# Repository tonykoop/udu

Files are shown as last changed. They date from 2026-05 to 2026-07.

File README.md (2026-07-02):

# Udu — Slip-Cast Ceramic Vessel Drum Family

> *Engineering documentation for a 3D-printed-master, plaster-mold, cone-6-stoneware slip-cast udu drum family — from dual-Helmholtz physics through the parametric design table to a manufacturable build packet.*

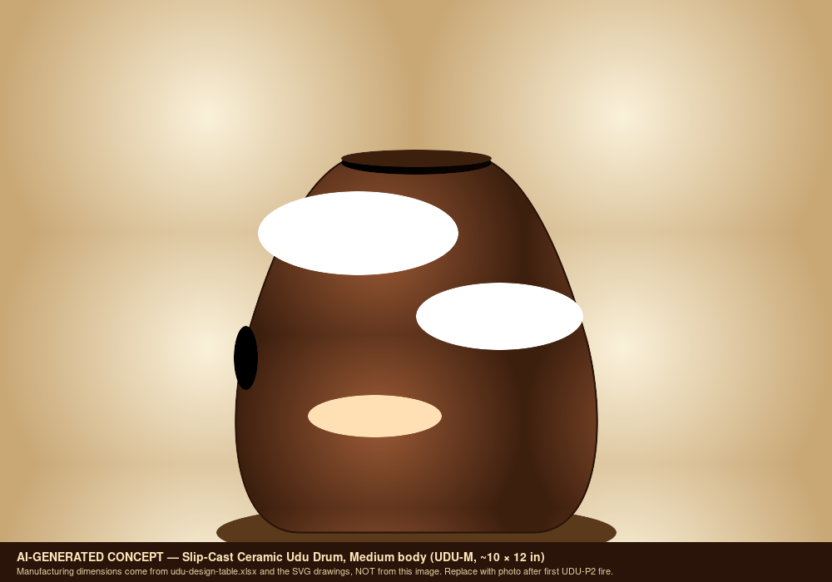
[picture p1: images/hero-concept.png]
Hero — AI-generated concept render of a Medium slip-cast udu (placeholder until first prototype is photographed)

*AI-generated concept render — replace with photo of first UDU-P2 (Medium) prototype after firing. Manufacturing dimensions come from the parametric design table, not from this image.*

## What this is

Engineering documentation for a four-size family (Small / Medium / Large / XL) of slip-cast ceramic udu drums, built around the **dual-Helmholtz coupled-resonator** model and a 3D-printed-master / plaster-mold / Cone-6-stoneware production pipeline. The repository combines:

1. **A parametric design table** ([`udu-design-table.xlsx`](udu-design-table.xlsx)) — body diameter, body height, wall thickness, mouth diameter, side-hole diameter, shape factor, shrinkage, and a four-size family-spec block with target mouth-tone and side-tone frequencies. Master scale factor `1/(1 - measured_shrinkage)` is parameterized; for a 12% shrinkage assumption, the master scales at ~1.136×.
2. **A v4.1 family-spec block** ([`family-spec.csv`](family-spec.csv)) — one row per family member (UDU-S/M/L/XL) with target frequencies, predicted frequencies from the dual-Helmholtz formula, cents-error per port, and the chamber-volume / port-area dimensions that drive both `cad/sw-design-table.xlsx` and `drawings/`.
3. **A full build packet** ([`design.md`](design.md), [`bom.csv`](bom.csv), [`sourcing.csv`](sourcing.csv), [`cut-list.csv`](cut-list.csv), [`validation.csv`](validation.csv), [`assembly-manual.md`](assembly-manual.md), [`supplier-rfq.md`](supplier-rfq.md), [`drawing-brief.md`](drawing-brief.md), [`visual-bom-brief.md`](visual-bom-brief.md), [`wolfram-starter.wl`](wolfram-starter.wl), [`risks.md`](risks.md)) — the same scaffold used across the [`tonykoop`](https://github.com/tonykoop) musical-instrument catalogue, with v4 red-team risk register added.
4. **A SolidWorks reference** ([`sw-reference/`](sw-reference/), [`cad/sw-design-table.xlsx`](cad/sw-design-table.xlsx)) — MasterLayout convention, global-equation list, design-table import procedure, and `Extract_Dimensions.swp` macro checklist. Round-trips `family-spec.csv` ↔ SolidWorks via the v4.1 SW workflow.
5. **A capstone slide deck, printable shop packet, and build-log site** ([`capstone-deck.pptx`](capstone-deck.pptx), [`print-packet.pdf`](print-packet.pdf), [`site/index.html`](site/index.html)) — three recruiter-facing artifacts that show the design is documented well enough that someone else could build it. The site is GitHub Pages compatible — drop `site/` into `docs/` to publish.

Sister repos: [`gemshorn`](https://github.com/tonykoop/gemshorn) (slip-cast horn-flute mold workflow), [`ocarina`](https://github.com/tonykoop/ocarina) (single-Helmholtz vessel-flute, sister slip-cast target), [`transverse-flute`](https://github.com/tonykoop/transverse-flute) (slip-cast workflow at larger scale), [`djembe`](https://github.com/tonykoop/djembe) (where Helmholtz-cavity-resonator analysis was originally derived for the bass tone), and [`instrument-maker`](https://github.com/tonykoop/instrument-maker) (the agent skill that generated this packet).

## Background — what makes the udu different

The udu (Igbo: *ụdụ*, "vessel") is a Nigerian clay-vessel drum: a closed ceramic body with a mouth at the top and a single side hole. Striking the mouth with a flat hand produces one resonant tone; striking the side hole produces another; opening, closing, and partly hand-covering each port lets the player slide and sweep between the two pitches. **It is not a generic ceramic bass pot.** Its lineage is specific and the documentation here treats that lineage as fact, not as marketing copy.

The governing model is **two coupled Helmholtz resonators sharing a chamber volume**:

```
f_top  = c/(2π) · √( A_top  / (V · L_top)  )
f_side = c/(2π) · √( A_side / (V · L_side) )
```

with `L = wall_thickness + 0.6·√(A/π)` (flanged-port end correction) and a coupling term that becomes important when both ports are partly open. Single-port formulas are useful **first-order** targets; the coupled-mode behavior — and especially the perceived pitch when a player's hand partly covers either port — has to be measured empirically. See [`design.md`](design.md) and [`wolfram-starter.wl`](wolfram-starter.wl) for the full treatment, including a placeholder eigenvalue model for coupled frequencies.

The practical consequence is that udu tuning is **two parametric pitches plus a player-coupled middle range**. Body volume sets the bass-end ceiling; port diameters set the upper bound; wall thickness and shape factor are secondary. Hand coupling is a sweep, not a discrete control — which is why the design table targets fall within ±50 ¢ rather than the ±25 ¢ used for fixed-pitch instruments like the ocarina.

## Family targets

The first prototype is the **Medium** body (10 in dia × 12 in tall, target mouth tone B3 ≈ 247 Hz, side tone G3 ≈ 196 Hz, chamber volume ≈ 440 in³). Once Medium voicing is stable, the same parametric model drives Small / Large / XL — see [`design.md`](design.md) and the family-spec block of [`udu-design-table.xlsx`](udu-design-table.xlsx).

| Model | Body diameter | Body height | Volume | Mouth tone | Side tone | Use |
|---|---:|---:|---:|---|---|---|
| **Small** | 8 in | 10 in | ~235 in³ | D♯4 | A3 | Tabletop, high tones |
| **Medium** *(prototype 1)* | 10 in | 12 in | ~440 in³ | B3 | G3 | Most versatile standard size |
| **Large** | 12 in | 14 in | ~739 in³ | G♯3 | D3 | Deep bass, traditional feel |
| **XL** | 14 in | 16 in | ~1149 in³ | F3 | C3 | Concert bass; needs stand |

Prototype ladder:

| Prototype | Goal | Success criteria |
|---|---|---|
| **UDU-P0** cup/port tile | Validate clay wall + tap behavior | No cracks; clear ceramic tap; clean port edge |
| **UDU-P1** Small body | Validate slip casting + side-hole slap | Measurable Helmholtz tones, comfortable slap edge |
| **UDU-P2** Medium body | Hit workbook Medium target | Mouth and side tones within ±50 ¢ post-bisque |
| **UDU-P3** Water udu | Pitch-bending volume variant | Smooth tilt-bend without leaking |
| **UDU-P4** Family molds | Scale S/M/L/XL | Predictable pitch trend across sizes |

## Hardware alignment — Bambu printer + ceramic kiln

This repo is one of the **slip-casting targets** for the in-flight Bambu printer + kiln pipeline. The build chain is:

1. Parametric design table sets fired-body dimensions.
2. Master scale factor `1/(1 - measured_shrinkage)` scales the master STL.
3. Bambu print master halves in PLA (or sealable resin); sand layer lines and seal. *Note: the Medium body is right at the edge of the Bambu X1C build envelope; XL will need a print farm split or outsourced master.*
4. Two-piece plaster mother mold around the sealed master.
5. Slip-cast Cone 6 stoneware → demold leather-hard → cut side hole undersized → bisque → tune → glaze (exterior only) → final fire.
6. Validate against [`validation.csv`](validation.csv); fold corrections back into the design table.

The same pipeline serves the [`ocarina`](https://github.com/tonykoop/ocarina), [`gemshorn`](https://github.com/tonykoop/gemshorn), and [`transverse-flute`](https://github.com/tonykoop/transverse-flute) repos.

## Repository structure

```
udu/
├── README.md                       ← you are here
├── LICENSE                         ← CC-BY 4.0
│
├── design.md                       ← dual-Helmholtz model, project intent, hardware alignment, prototype ladder
├── udu-design-table.xlsx           ← parametric spreadsheet (formulas, blue inputs, family block)
├── family-spec.csv                 ← S/M/L/XL family-spec rows (v4 family-aware design)
├── risks.md                        ← red-team risk register (v4 — acoustic/structural/ergonomic/supply/fit-finish)
│
├── bom.csv                         ← bill of materials
├── sourcing.csv                    ← supplier/search tracker
├── cut-list.csv                    ← rough/finished dimensions, tolerances, family scaling
├── validation.csv                  ← target/measured tuning + cents-error log
├── supplier-rfq.md                 ← RFQ template for slip / plaster / consumables
│
├── assembly-manual.md              ← shop-floor build sequence
├── drawing-brief.md                ← required views + critical dimensions for CAD
├── visual-bom-brief.md             ← visual-BOM art-direction brief
├── wolfram-starter.wl              ← dual-Helmholtz physics starter notebook
│
├── capstone-deck.{md,pptx}         ← capstone slide deck (15 slides — v4.1 watch-points)
├── print-packet.{md,html,pdf}      ← combined print-ready shop packet
├── capstone-manifest.json          ← orientation manifest
│
├── sw-reference/                   ← SolidWorks MasterLayout convention, equation list, import procedure
├── cad/                            ← parametric body OpenSCAD starter + sw-design-table.xlsx (v4.1)
├── cad/dimensions/                 ← Extract_Dimensions.swp macro CSV captures
├── cnc/                            ← (deferred — slip-cast does not need CNC unless turning a wooden master)
├── drawings/                       ← SVG drawings: per-member body, family-overview, mold split, section
├── images/                         ← AI-generated concept renders (placeholders)
└── site/                           ← build-log static site (HTML+CSS, GitHub Pages compatible)
```

## Status

**Status:** L1 concept packet — internally called a "V5 explorer/readiness
packet" (see below). This repository is not yet a full V5 build-packet
candidate (not L2) because fired prototype measurements, DXF exports,
CAD-derived renders, an exploded diagram, an annotated assembly plate, and
real MCP provenance rows are still missing. See
[`docs/v5-readiness.md`](docs/v5-readiness.md) and
[`visual-output-register.csv`](visual-output-register.csv).

| Section | Status |
|---|---|
| Parametric design table + dual-Helmholtz model | ✓ done |
| **Family-spec.csv (S/M/L/XL with predicted vs target Hz)** | ✓ done — v4.1 |
| **Risks.md (red-team risk register, 5 categories)** | ✓ done — v4.1 |
| Build packet (BOM / sourcing / cut-list / validation / RFQ) | ✓ done |
| Assembly manual + drawing brief | ✓ done |
| Wolfram physics starter (with coupled-mode placeholder) | ✓ done |
| Capstone deck + print packet | ✓ done — v4.1 (15 slides; Project Intent / Physics / Hardware Alignment / Family Spec) |
| **Build-log static site (`site/index.html`)** | ✓ done — v4.1 |
| Concept renders (AI-generated, captioned) | ✓ done (placeholders) |
| Parametric CAD (OpenSCAD starter, family-aware) | ✓ done (master-shape only) |
| **SolidWorks design table + sw-reference/** | ✓ done — v4.1 |
| Dimensioned drawings (SVG, per family member + family-overview) | ✓ done — v4.1 |
| Production-ready CAD (.step / .stl) | **deferred** — generated after empirical Medium-body validation |
| Coupled-mode tuning model (eigenvalue fit) | **deferred** — needs Phase-1 measured data |
| First UDU-P1 (Small) prototype build | forthcoming (Bambu + kiln pipeline) |

Tier 3 production files (.step, validated .stl, .dxf, .gcode) are **out of scope until UDU-P2 (Medium) validates wall thickness and port-pitch behavior**. See [`design.md`](design.md) "Open Assumptions" for the deferral reasoning.

### v4.1 escalations

The red-team pass surfaced four high-severity items that block declaring this packet "production-tagged" (see [`risks.md`](risks.md)):

| ID | Description | Action |
|---|---|---|
| ACO-01 | Family-extreme target mismatch (UDU-S +157 ¢ sharp, UDU-XL -220 ¢ flat) | Adjust port diameters per size *or* shift family targets onto an acoustically-honest ladder |
| STR-02 | UDU-XL greenware crack risk on long unsupported wall | Wall thickness 0.40 in for XL only after first XL casting confirms crack initiation |
| SUP-02 | UDU-L / UDU-XL master halves exceed Bambu X1C build envelope | Outsource print *or* multi-section master *or* defer L/XL until print farm grows |
| CUL-01 | Igbo lineage attribution requires pre-publication review | Sign-off recorded in `notes/` before site goes live on GitHub Pages |

## License

Released under [CC-BY 4.0](LICENSE) — original written content, design files, photographs, and physics work in this repository are mine, free to reuse and adapt with credit.

The **udu** as an instrument concept and name belongs to the Igbo people of Nigeria; the lineage attribution in [`design.md`](design.md) is part of the documentation, not a license claim.

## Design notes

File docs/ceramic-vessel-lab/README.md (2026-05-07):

# Ceramic Vessel Lab Addendum - Udu

This folder preserves the brainstorm/design packet that was developed in the shared `instrument-maker` workspace before the material was copied into the dedicated `udu` repo.

Use the repo-root files for the current production packet:

- `../../design.md`
- `../../udu-design-table.xlsx`
- `../../bom.csv`
- `../../sourcing.csv`
- `../../validation.csv`
- `../../assembly-manual.md`
- `../../print-packet.pdf`
- `../../capstone-deck.pptx`

Use this addendum for the earlier ceramic-vessel research framing:

- `design.md` - dual Helmholtz udu notes, family sizes, prototype ladder, and workbook cleanup ideas.
- `assembly-manual.md` - slip-cast prototype workflow.
- `bom.csv`, `sourcing.csv`, `validation.csv` - structured lab tables.
- `drawing-brief.md`, `visual-bom-brief.md` - documentation and image planning.
- `wolfram-starter.wl` - compact Helmholtz model starter.
- `Udu-brainstorm-design-table.xlsx` - copied source workbook from the shared brainstorm.
- `ceramic-vessel-instrument-lab.md` - cross-instrument ceramic vessel roadmap.

Nothing in this addendum overwrites the root-level v4 packet; it is here as provenance and research context.

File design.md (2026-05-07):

# Slip-Cast Ceramic Udu Drum Family

## Source

- Design table: `udu-design-table.xlsx` (Master_Inputs + Design_Table sheets)
- Family spec: `family-spec.csv` (S/M/L/XL members)
- SW reference: `sw-reference/` (MasterLayout convention, equation list, design-table import procedure)
- Workbook lineage: `docs/Udu.xlsx`, sheet `Udu Drum Family`, inspected range `A1:H146`
- Workbook content observed: design inputs, dual-Helmholtz calculator, four-size family, variants, playing techniques, ceramic production workflow, BOM, design notes, Wolfram notebook notes.

## Project Intent

Build a slip-cast ceramic udu family — Small / Medium / Large / XL — with
repeatable chamber volumes and two playable Helmholtz tones: the main mouth
tone and the side-hole slap tone. The first production target is the
**Medium** standard udu (UDU-P2: 10 in × 12 in body, B3 mouth / G3 side),
followed by a scaled family. The udu (Igbo: *ụdụ*, "vessel") is a Nigerian
clay-vessel drum and the documentation here treats that lineage as fact, not
marketing.

The repository is the engineering artifact for the dual-Helmholtz coupled-
resonator model: parametric design table → 3D-printed master halves →
two-piece plaster mold → Cone-6 stoneware slip-cast → bisque + tune + glaze.
The same pipeline serves `ocarina/`, `gemshorn/`, and `transverse-flute/`.

## Governing Model

The udu uses a shared chamber with two coupled Helmholtz resonators:

```text
f_top  = c/(2*pi) * sqrt( A_top  / (V * L_top)  )
f_side = c/(2*pi) * sqrt( A_side / (V * L_side) )
L      = wall_thickness + 0.6 * sqrt(A/pi)
V      = (pi/6) * body_diam^2 * body_height * shape_factor
```

When both ports are open and the player's hands move, the modes couple — the
single-port formulas are useful first-order targets, and the placeholder
coupled-mode eigenvalue model lives in `wolfram-starter.wl`. Measured
prototypes define the final tuning corrections; per-family corrections feed
back through `scripts/record_measurement.py` (see
`references/empirical-learning-loop.md`).

## Hardware Alignment

This repo is one of the slip-cast targets for the in-flight Bambu printer +
ceramic kiln pipeline shared with `ocarina/`, `gemshorn/`, and
`transverse-flute/`. The build chain:

| Stage | Tool / pipeline | Notes |
| --- | --- | --- |
| Design table | `udu-design-table.xlsx` Master_Inputs | Blue cells = inputs; volume formula derived |
| Master scaling | `master_scale_factor = 1/(1 - measured_shrinkage)` | Re-derive per slip batch — see risks.md SUP-01 |
| Master print | Bambu X1C (UDU-S, UDU-M) or outsourced print (UDU-L, UDU-XL) | X1C envelope ≈ 256 mm; L/XL exceed it — see risks.md SUP-02 |
| Mold | Two-piece plaster mother mold, USG #1 pottery plaster | Split line off the hand-contact equator |
| Cast | Cone 6 stoneware casting slip | Shrinkage coupon required per batch |
| Trim | Side hole cut at leather-hard, undersized | Final tune at bisque |
| Fire | Cone 06 bisque → Cone 6 glaze | Glaze exterior only |
| Validate | `validation.csv` mouth/side/coupled measurements | `record_measurement.py` updates per-family corrections |
| CAD round-trip | `UDU-000_MasterLayout.SLDPRT` ↔ `cad/sw-design-table.xlsx` | See `sw-reference/` for the SW workflow |

## Current Workbook Inputs

| Field | Current value |
| --- | --- |
| Body diameter | 10 in |
| Body height | 12 in |
| Wall thickness | 0.3 in |
| Mouth diameter | 3 in |
| Side hole diameter | 2 in |
| Shape factor | 0.7 |
| Clay body | Cone 6 stoneware |
| Shrinkage | 0.12 |
| Speed of sound | 13510 in/s |

## Current Family Targets

| Model | Diameter | Height | Volume | Mouth tone | Side tone | Use |
| --- | ---: | ---: | ---: | --- | --- | --- |
| Small | 8 in | 10 in | 235 in3 | D#4 | A3 | Tabletop and high tones |
| Medium | 10 in | 12 in | 440 in3 | B3 | G3 | Most versatile standard size |
| Large | 12 in | 14 in | 739 in3 | G#3 | D3 | Deep bass and traditional feel |
| XL | 14 in | 16 in | 1149 in3 | F3 | C3 | Concert bass, likely needs stand |

## Critical Design Features

- Body volume controls both main tones; slip casting is valuable because it makes volume repeatable.
- Port diameters and effective neck lengths are the main pitch controls.
- Wall thickness controls shell tap tone, durability, drying risk, and weight more than Helmholtz pitch.
- The side hole edge must be comfortable for repeated hand slaps.
- The mouth rim should be rounded enough for comfort but consistent enough for repeatable hand sealing.
- Feet, stand interface, or flat area should be designed before the mold if the instrument needs stability.

## Cultural And Product Note

The udu has Igbo roots and is not just a generic ceramic bass pot. Public-facing copy should be respectful, specific, and verified before publication. For Tony's own build docs, keep the lineage note visible and separate it from product marketing.

## Mold Strategy

Recommended first production mold:

- Two-piece plaster body mold split near the widest diameter.
- Separate mouth/neck core or hand-cut mouth after demold if that gives cleaner release.
- Side hole cut at leather-hard stage so tuning can be adjusted by cutter size and file work.
- Smooth mold split where hand contact will happen.
- Add subtle foot pads or a stand-contact feature if the final instrument should sit safely.

Master scale factor:

```text
scale = 1/(1 - shrinkage)
```

For 12 percent shrinkage, use approximately `1.136` before adjusting for measured clay data.

## Prototype Ladder

| Prototype | Goal | Success criteria |
| --- | --- | --- |
| UDU-P0 cup/port tile | Validate clay wall/tap behavior | No cracks; clear ceramic tap; clean port edge |
| UDU-P1 small body | Validate slip casting and side-hole slap | Measurable Helmholtz tone, comfortable slap edge |
| UDU-P2 medium body | Hit workbook medium target | Mouth and side tones within +/-50 cents after bisque |
| UDU-P3 water udu | Explore pitch-bending volume | Smooth tilt-bend without leaking or handling risk |
| UDU-P4 family molds | Scale S/M/L/XL | Predictable pitch trend across sizes |

## Workbook Improvement Notes

Recommended next workbook additions:

1. Add measured frequency and cents-error fields for mouth, side hole, and both-open condition.
2. Add cast-wall thickness measured at rim, shoulder, belly, and foot.
3. Add water-fill chamber volume after bisque and glaze fire.
4. Add per-size CAD master dimensions and shrinkage-compensated dimensions.
5. Add a coupled-mode experiment table for both ports open, side port covered, and mouth hand-muted.

## Open Assumptions

- Workbook costs are estimates and have not been date-checked.
- The side-hole tuning note in the workbook should be validated empirically; for a simple Helmholtz port, enlarging a port usually raises its open-port resonance, but hand coupling can make perceived playing behavior more complicated.
- Exact mold split and pour/drain design depend on final body shape.

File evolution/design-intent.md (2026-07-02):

# Design Intent — udu rev A

- Master CAD: `cad/udu_master.scad` (sha256: 3ec045b758e5cc83f53b8c541f76a32af287d74531ad54095fb4cc0465b52187), driven by `family-spec.csv` (sha256: 79fac1c96f1760c02ea0c0ca49da3dd99e11b8f3c57aff36c2de8a3d846eea4a)
- Function: Slip-cast ceramic dual-port vessel drum family (UDU-S/M/L/XL). The chamber volume plus mouth and side ports form a coupled dual-Helmholtz resonator; the player strikes the side port for the bass "water" tone and the body for slaps. Fired geometry, not green geometry, is acoustic authority — the master carries `master_scale_factor = 1.136` for cone-6 stoneware 12% shrinkage.
- Environment: hand percussion, indoor; ceramic body is brittle (drop risk); fired-clay dimensional variance dominates tolerance.
- Target qty: 1 per family member (prototypes). Deadline: TBD. Budget/unit ceiling: TBD.

## Critical dimensions (carry tolerances)

| Feature | Nominal (UDU-M) | Tolerance | Why critical | Source |
| --- | --- | --- | --- | --- |
| Chamber volume | 439.8 cu in | fired-volume measurement gate | sets both port pitches | family-spec.csv (measurement_required) |
| Mouth diameter | 3.0 in | port-edge measurement gate | mouth Helmholtz pitch | family-spec.csv |
| Side port diameter | 2.0 in | port-edge measurement gate | side/bass pitch | family-spec.csv |
| Wall thickness | 0.30 in | slip-cast control | structure + tone | family-spec.csv |
| Master scale factor | 1.136 | verify with fired shrinkage coupons | green→fired dimensional authority | cad/udu_master.scad |

## Incidental (free for DFM)

- Surface texture/burnish, decorative banding, exact foot profile.

## Must-nots (DFM may never violate)

- Do not treat green (unfired) dimensions as acoustic authority — all pitch predictions apply to FIRED geometry.
- Port edges must stay smooth/radiused per slip-cast plan; sharp fettled edges shift port behavior.
- No member may be promoted past measurement_required until fired-volume and port measurements land (family-spec dimension_provenance).

## Material intent

- Preferred: Cone 6 stoneware, 12% shrinkage (family-spec.csv). Substitutions require new shrinkage factor + re-prediction.

## Stage status

Stage 0 intake complete 2026-07-01. Gate A (Alpha shop compile) NOT run — no concessions logged.

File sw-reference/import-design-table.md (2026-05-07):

# Importing the Udu Design Table into SolidWorks

The design table at `cad/sw-design-table.xlsx` is generated from
`family-spec.csv` by `scripts/generate_sw_design_table.py` (in the
instrument-maker-v4 skill). Re-run the generator any time
`family-spec.csv` changes.

## One-time wiring (per part)

1. Open `UDU-000_MasterLayout.SLDPRT` in SolidWorks.
2. Verify the global equations from
   [`MasterLayout-equations.txt`](MasterLayout-equations.txt) are
   present in `Tools > Equations > Manage Equations > Global Variables`.
   Any missing global must be added by hand before the design table
   imports cleanly.
3. `Insert > Tables > Design Table > From Existing File`.
4. Browse to `../cad/sw-design-table.xlsx` and select.
5. SolidWorks reads the file and shows the configurations to import:
   - `MASTER_TEMPLATE`
   - `UDU-S`
   - `UDU-M`
   - `UDU-L`
   - `UDU-XL`
6. Click `OK` in the configurations dialog.
7. Right-click each configuration in `ConfigurationManager` and
   `Show Configuration` to verify the rebuild succeeds.

## Verification after import

After import, open `Tools > Evaluate > Mass Properties` for each
configuration in turn. The `chamber_volume_cuin` global should match
the volume you'd compute by hand from `body_diam_in`, `body_height_in`,
and `shape_factor`. Differences >1% mean the SW geometry has drifted
from the formula — investigate before accepting the import.

## Updating after a `family-spec.csv` edit

```bash
# Regenerate the SW design table xlsx
python3 /path/to/skill/scripts/generate_sw_design_table.py \
  C:\Users\Tony\Documents\GitHub\udu \
  --output cad/sw-design-table.xlsx \
  --part-name UDU-000_MasterLayout
```

Then in SolidWorks:

1. Right-click the existing design table in `ConfigurationManager`.
2. `Edit Table > Configurations` — SW asks if you want to keep current
   values or re-read from the file. Choose **re-read from file**.
3. Verify that no configuration broke during the re-read; activate each
   in turn to test rebuild.
4. If a configuration fails to rebuild, the most common cause is a new
   global referenced in the design table that wasn't added to
   `Tools > Equations` first — go back to step 2 of the one-time wiring.

## Drift detection

After making non-trivial changes in SW (sketch reorganization,
feature splits), capture the SW state before and after with the macro
and diff:

```bash
# Before edit
# (run Extract_Dimensions.swp in SW; save CSV as cad/dimensions/before-<date>.csv)

# After edit
# (run Extract_Dimensions.swp in SW; save CSV as cad/dimensions/after-<date>.csv)

python3 /path/to/skill/scripts/ingest_dimension_csv.py \
  --csv cad/dimensions/after-<date>.csv \
  --workbook udu-design-table.xlsx \
  --design-sheet Master_Inputs \
  --tolerance-percent 0.5 \
  --report sw-reference/drift-<date>.md
```

Any unintended dimension change shows up in the drift report and gets
escalated.

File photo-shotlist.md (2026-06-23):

# Photo Shot List — Udu — Slip-Cast Ceramic Vessel Drum Family

> **Status: placeholder** — record actual photos in `visual-output-register.csv`
> as the build progresses.

## Pre-Build

- [ ] Raw materials laid out (shell stock, head, hardware).
- [ ] Cut list parts arranged in order.
- [ ] Jigs and fixtures in position.

## During Build

- [ ] Stave dry-fit (top view showing roundness and gap).
- [ ] Glue-up with clamps in place.
- [ ] Bearing edge after sanding (close-up).
- [ ] Hardware drilling and fitting.
- [ ] Head first mount (hand-tension, before tuning).

## Finished Instrument

- [ ] Hero: full instrument, neutral background, natural light, scale reference.
- [ ] Top view (head face).
- [ ] Side profile (full height).
- [ ] Hardware detail (lug / rope / rod close-up).
- [ ] Playing position (held or mounted).

## Post-Validation

- [ ] Tuner and instrument in frame (showing pitch reading).
- [ ] Player's hand position on head.

## File Naming

`udu-[stage]-[sequence].jpg` — e.g., `udu-build-01.jpg`, `udu-hero-01.jpg`.
Record each in `visual-output-register.csv` with authority label `build_photo`.

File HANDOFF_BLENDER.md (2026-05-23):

# Handoff: Model an Udu drum in Blender (V5 pipeline pilot)

## Who you are

You are Claude Desktop with Blender MCP. You're picking up the V5 build-packet work for the Udu drum repo. This handoff is self-contained — you don't have prior conversation context.

## Background

Udu is a Nigerian Igbo clay pot drum. The acoustically important features:
- A hollow body — egg/gourd profile, axially symmetric (a revolve of a 2D profile around the vertical axis)
- A **top neck** (spout) — open cylinder, the primary tone hole
- A **side hole** (ihota) — circular opening cut into the body wall, hand-modulated for pitch bend
- Walls of nominal 8–12 mm clay thickness

Frank Giorgini's modern udu family has named variants (Udongo, Hadgini, Tambuta, Mbwata) that differ in proportion. Aim for **Hadgini** (tall-narrow form) as the first model — it's the most recognizable silhouette.

Reference exemplar style: photoreal studio product photo, dark reddish-brown clay finish with a subtle hand-textured surface, slight specular highlight, soft warm key light, dark wood surface, shallow depth of field. Think Smithsonian catalog or Frank Giorgini's own photography.

## Where files live

Working directory on the host: `C:\Users\Tony\Documents\GitHub\udu\` (WSL: `/mnt/c/Users/Tony/Documents/GitHub/udu/`).

Create these subfolders if missing: `cad/`, `images/`, `images/blender-scenes/`, `images/material-study/`.

## Geometry (starter values — refine as you go)

For the Hadgini variant:

| Parameter | Value | Notes |
|---|---|---|
| `body_height_mm` | 330 | floor of body to start of neck |
| `body_max_diameter_mm` | 220 | widest point, ~45% up from base |
| `body_max_dia_height_frac` | 0.45 | fraction of body height at widest point |
| `base_diameter_mm` | 110 | flat-ish bottom for stability |
| `shoulder_diameter_mm` | 140 | where neck meets body |
| `neck_height_mm` | 80 | open cylinder above shoulder |
| `neck_id_mm` | 55 | inner diameter of mouth |
| `neck_od_mm` | 75 | outer diameter — wall is 10 mm |
| `wall_thickness_mm` | 10 | uniform clay wall |
| `side_hole_diameter_mm` | 65 | the ihota |
| `side_hole_height_mm` | 200 | center of side hole, measured from base |
| `side_hole_angle_deg` | 0 | facing camera in default 3/4 view |

These are starter values consistent with Hadgini-class proportions; treat the design-table at `C:\Users\Tony\Documents\GitHub\udu\udu-design-table.xlsx` as authoritative if it exists, otherwise propose these as the seed.

## Tasks (in order)

### 1. Build the parametric model in Blender

- Create a 2D profile curve in the XZ plane traced through the points above (base → max-diameter → shoulder).  
  Smooth it with a Bezier spline; the silhouette should be a clean teardrop, not a kink.
- Use **Spin** (or a Screw modifier with 360° and steps=64) to revolve the profile around the Z axis. Result: a closed shell, no top, no bottom.
- **Solidify** with thickness = `wall_thickness_mm` (10 mm, offset = -1 so thickness grows inward from the visible surface).
- Add the **top neck**: cylinder, OD 75, ID 55, height 80, sitting on the shoulder, booleaned-union with the body.
- Add the **side hole**: a cylinder of OD ≥ wall thickness × 2, passing through the body wall at the height/angle above, then **Boolean Difference** from the body. The hole should be cleanly punched, no fragmented faces.
- Verify the inside is hollow (cutaway view through Solidify); no internal walls.

Save the .blend file to `images/blender-scenes/udu-hadgini-master.blend`.

### 2. Render the hero shot

- 2048 × 1536, sRGB, Cycles or Eevee (state which).
- Camera: 3/4 view, slightly below shoulder height, looking at the side hole.
- Lighting: HDRI studio environment + a soft warm key light from camera-left.
- Material: PrincipledBSDF with `Base Color` ≈ #5a3225 (dark reddish clay), `Roughness` 0.7, slight `Bump` from a Voronoi or Musgrave noise to simulate hand-burnished clay surface.
- Floor: dark walnut wood with subtle reflection.

Save the render to `images/hero-render.png`.

### 3. Render the exploded diagram

- Same camera and lighting.
- Translate the **neck** straight up by ~120 mm.
- Translate the **side-hole cylinder** (or its negative as a labeled component) outward along its axis by ~80 mm to show it as a separate "removed" piece.
- Save to `images/exploded-diagram.png`.

(Numbered callouts can be added in Photoshop later via the Adobe MCP pipeline — don't do that in Blender.)

### 4. Material study

Re-render the hero camera/lighting with three clay variants. Save as:
- `images/material-study/clay-dark.png` — base #5a3225 (Hadgini)
- `images/material-study/clay-terracotta.png` — base #b85c3a (lighter Tambuta look)
- `images/material-study/clay-black-burnished.png` — base #1f1818, roughness 0.4 (high-fired smoke finish)

Same camera, same lighting — only the material changes.

### 5. Write the provenance log

Create / append to `cad/mcp-session-log.md` with this header if missing:

```
| timestamp | tool | artifact | session_id | parent_artifact | notes |
|-----------|------|----------|------------|------------------|-------|
```

Add a row for each file you produced. Use ISO-8601 UTC for `timestamp`, `blender` for `tool`, your Claude Desktop conversation ID if exposed (else `unknown`) for `session_id`, and the upstream file for `parent_artifact` (e.g., parent of `hero-render.png` is `images/blender-scenes/udu-hadgini-master.blend`).

### 6. Update the visual-output register

If `visual-output-register.csv` doesn't exist, create it with this header:

```
artifact_id,path,artifact_kind,role,authority,dimension_claim
```

Add a row for each rendered PNG with `artifact_kind=render_preview`, `role=concept`, `authority=non_fabrication`, `dimension_claim=non_authoritative`. Add one row for the .blend file with `artifact_kind=cad`, `role=fabrication_geometry`, `authority=fabrication`, `dimension_claim=traceable_to_design_table` *only if* you sourced the geometry from `udu-design-table.xlsx`; otherwise mark it `dimension_claim=seed_values`.

## Acceptance gates

- [ ] `images/blender-scenes/udu-hadgini-master.blend` checked in, reopens cleanly
- [ ] `images/hero-render.png` exists, 2048×1536, recognizable as an udu drum
- [ ] `images/exploded-diagram.png` exists, neck + side-hole visibly separated
- [ ] `images/material-study/*.png` — three clay variants, same camera
- [ ] `cad/mcp-session-log.md` has one row per produced file
- [ ] `visual-output-register.csv` has matching rows
- [ ] No PNG marked as fabrication authority (these are concept-only)

## What to do if you get stuck

- If a Boolean Difference produces a fragmented hole, switch the body to "Solidify after the boolean" instead of before, or use the Knife Project workflow with a cylinder cap.
- If the silhouette looks too "vase-like" rather than "udu-like," reduce `shoulder_diameter_mm` to ~120 and ensure the curve has a clear narrowing between body-max and shoulder.
- If your Blender MCP session times out, save the .blend frequently and report which step you reached.

## Where this fits

- Repo issue: **tonykoop/udu#1** — Generate V5 build packet
- V5 spec: **tonykoop/instrument-maker#178**
- Blender pipeline contract: **tonykoop/instrument-maker#180**
- Provenance schema: **tonykoop/instrument-maker#183**

When done, comment on **tonykoop/udu#1** with the produced file list and a thumbnail of the hero render.

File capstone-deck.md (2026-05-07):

# Slip-Cast Ceramic Udu Drum Family — v4.1 Capstone
- Musical instrument documentation capstone
- Build packet: udu
- Generated: 2026-05-07

---

# Project Intent
- Build a slip-cast ceramic udu family — Small / Medium / Large / XL — with
repeatable chamber volumes and two playable Helmholtz tones: the main mouth
tone and the side-hole slap tone. The first production target is the
**Medium** standard udu (UDU-P2: 10 in × 12 in body, B3 mouth / G3 side),
followed by a scaled family. The udu (Igbo: *ụdụ*, "vessel") is a Nigerian
clay-vessel drum and the documentation here treats that lineage as fact, not
marketing.

_Speaker notes:_ Read design.md before committing to dimensions or sourcing decisions.

---

# Physics Model
- The udu uses a shared chamber with two coupled Helmholtz resonators:

```
f_top  = c/(2*pi) * sqrt( A_top  / (V * L_top)  )
f_side = c/(2*pi) * sqrt( A_side / (V * L_side) )
L      = wall_thickness + 0.6 * sqrt(A/pi)
V      = (pi/6) * body_diam^2 * body_height * shape_factor
```

_Speaker notes:_ Governing equations extracted verbatim from design.md. Apply empirical corrections (NAF K2, scale offsets) only where the model permits — see references/acoustic-models.md.

---

# Hardware Alignment
- This repo is one of the slip-cast targets for the in-flight Bambu printer +
ceramic kiln pipeline shared with `ocarina/`, `gemshorn/`, and
`transverse-flute/`. The build chain:

| Stage | Tool / pipeline | Notes |
| --- | --- | --- |
| Design table | `udu-design-table.xlsx` Master_Inputs | Blue cells = inputs; volume formula derived |
| Master scaling | `master_scale_factor = 1/(1 - measured_shrinkage)` | Re-derive per slip batch — see risks.md SUP-01 |
| Master print | Bambu X1C (UDU-S, UDU-M) or outsourced print (UDU-L, UDU-XL) | X1C envelope ≈ 256 mm; L/XL exceed it — see risks.md SUP-02 |
| Mold | Two-piece plaster mother mold, USG #1 pottery plaster | Split line off the hand-contact equator |
| Cast | Cone 6 stoneware casting slip | Shrinkage coupon required per batch |
| Trim | Side hole cut at leather-hard, undersized | Final tune at bisque |
| Fire | Cone 06 bisque → Cone 6 glaze | Glaze exterior only |
| Validate | `validation.csv` mouth/side/coupled measurements | `record_measurement.py` updates per-family corrections |
| CAD round-trip | `UDU-000_MasterLayout.SLDPRT` ↔ `cad/sw-design-table.xlsx` | See `sw-reference/` for the SW workflow |

_Speaker notes:_ Identifies which shop pipeline(s) this instrument lives in: Bambu+kiln slip-cast, 40W laser flat-pack, CNC+lathe, segmented turning, drum-skin work, or hybrid combinations.

---

# How To Use This Packet
- Start with design.md for intent and assumptions.
- Use bom.csv, sourcing.csv, and cut-list.csv before buying or cutting.
- Use drawing-brief.md and CAD/CNC folders before machining.
- Print the packet for shopping, shop work, and validation.

---

# File Map
- design.md: Project intent, catalog metadata, assumptions, and validation plan.
- bom.csv: Starter bill of materials with part categories, quantities, drawing refs, and notes.
- sourcing.csv: Supplier/search tracker with specs, price/date fields, lead time, substitutes, and risks.
- cut-list.csv: Rough/final stock sizes, material, grain/orientation, operations, yield, and offcuts.
- drawing-brief.md: Manufacturing drawing and technical product sketch brief.
- assembly-manual.md: Shop-facing sequence, tools, fixtures, safety, tuning, finishing, and maintenance notes.
- validation.csv: Target/measured values, tolerance, environment, result, and tuning/build action log.
- supplier-rfq.md: Supplier email/request-for-quote starter.

---

# Family Spec

| member_id | target_note_mouth | target_hz_mouth | target_note_side | target_hz_side | body_diam_in | body_height_in | wall_thk_in | mouth_diam_in | side_diam_in | shape_factor | chamber_volume_cuin | predicted_hz_mouth | predicted_hz_side | cents_error_mouth | cents_error_side | master_scale_factor | clay_body | shrinkage_pct | reference_repo | notes |
| --- | --- | --- | --- | --- | --- | --- | --- | --- | --- | --- | --- | --- | --- | --- | --- | --- | --- | --- | --- | --- |
| UDU-S | D#4 | 311.13 | A3 | 220.00 | 8.0 | 10.0 | 0.30 | 3.0 | 2.0 | 0.70 | 234.6 | 340.8 | 262.4 | +157 | +304 | 1.136 | Cone 6 stoneware | 12 | udu | Small/tabletop. Predictions sharp of targets — mouth dia likely needs to drop ~2.5 in OR shape factor increased to reduce predicted Hz; flag for empirical UDU-P1 measurement. |
| UDU-M | B3 | 246.94 | G3 | 196.00 | 10.0 | 12.0 | 0.30 | 3.0 | 2.0 | 0.70 | 439.8 | 248.9 | 191.6 | +14 | -39 | 1.136 | Cone 6 stoneware | 12 | udu | Medium/standard. Workbook prototype-1 target. Predictions within ±50¢ of targets — hits the v4 design-table band. |
| UDU-L | G#3 | 207.65 | D3 | 146.83 | 12.0 | 14.0 | 0.30 | 3.0 | 2.0 | 0.70 | 738.8 | 192.1 | 148.0 | -126 | +14 | 1.136 | Cone 6 stoneware | 12 | udu | Large/deep bass. Mouth prediction flat of target — port may need to enlarge slightly OR shape factor reduced; flag for empirical UDU-L measurement. |
| UDU-XL | F3 | 174.61 | C3 | 130.81 | 14.0 | 16.0 | 0.30 | 3.0 | 2.0 | 0.70 | 1148.7 | 153.9 | 118.5 | -220 | -172 | 1.136 | Cone 6 stoneware | 12 | udu | Concert bass. Predictions flat across both ports — XL may need port scaling (mouth 3.5+ in) to recover pitch; needs stand. Flag as design risk — see risks.md. |

_Speaker notes:_ Sizes scale via the master scale factor; tuning targets are first-order Helmholtz/cantilever predictions to be empirically corrected per prototype.

---

# Build Workflow
- Design and assumptions
- Source materials and hardware
- Prepare stock, fixtures, and CNC/laser/lathe setup
- Assemble, tune, finish, and validate

---

# Sourcing And BOM
- BOM gives part categories and drawing references.
- Sourcing tracks search terms, supplier candidates, price/date, lead time, substitutions.
- Visual BOM brief turns the parts list into a presentation-ready image board.

---

# Shop Packet
- Cut list for lumber/sheet/blank planning.
- Assembly manual for away-from-keyboard work.
- Validation sheet for measured dimensions, tuning, pass/fail checks.

---

# Drawings, CAD, CNC
- drawing-brief.md defines required views, dimensions, datums, sketch intent.
- cad/ holds models and design tables.
- cnc/ holds CAM, toolpaths, setup sheets, dry-run notes.
- drawings/ holds PDFs, SVGs, DXFs, drawing exports.






---

# Images And Screenshots
- images/family-overview-concept.png
- images/family-overview-concept.svg
- images/hero-concept.png
- images/hero-concept.svg

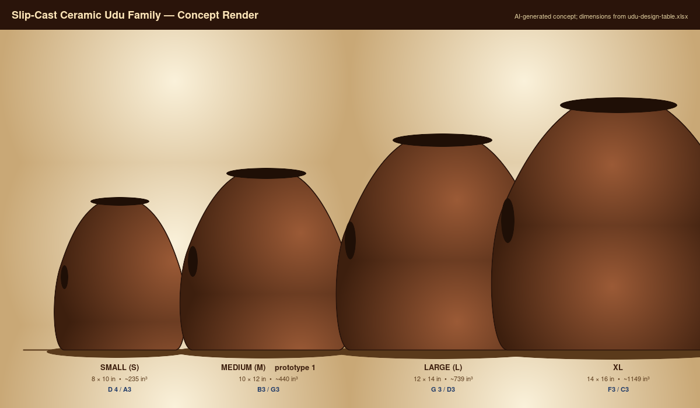
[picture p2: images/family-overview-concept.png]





---

# Validation Plan
- A4 = 440 Hz reference check.
- Tuning targets logged in validation.csv.
- Critical dimensions verified against design sheet and CAD.
- Photos and revision notes after each major step.

---

# Open Risks / Decisions
- TBDs in design sheet and BOM.
- Supplier price/availability not yet verified.
- Generated images marked as concept placeholders.
- Empirical corrections await measured prototype data.

---

# Next Actions
- Replace TBDs with measured/source-backed values.
- Verify live supplier price and availability before buying.
- Export final drawings and visual BOM images.
- Regenerate this deck and print packet after final edits.

---

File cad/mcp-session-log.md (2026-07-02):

# MCP Session Log

This repository has no recorded V5 MCP production sessions yet.

| timestamp_utc | tool | role | artifact | session_id | parent_artifact | authority | notes |
| --- | --- | --- | --- | --- | --- | --- | --- |
| 2026-05-18T00:00:00Z | none | readiness_inventory | capstone-manifest.json | n/a | repository files | non_fabrication | Round 30 inventory only. No OpenSCAD MCP, Blender MCP, Illustrator MCP, Photoshop MCP, Adobe MCP, or image-gen-2 session was run in this lane. |
| 2026-05-18T00:00:00Z | none | readiness_inventory | explorer.html | n/a | repository files | non_fabrication | Explorer summarizes existing v4.1 evidence and remaining V5 gates. |
| 2026-07-01T00:00:00Z | claude-code (Fable 5) | packet_refresh | udu-design-table.xlsx | fable-v5-refresh-2026-07-01 | family-spec.csv | fabrication | V5 refresh provenance log-only pass: confirms visual-output-register.csv DT-001 authority=fabrication; no dimension changes made. No CAD/MCP tooling was run against this workbook in this session. |
| 2026-07-01T00:00:00Z | none (pre-existing, kept as-is) | packet_refresh | cad/udu_master.scad | fable-v5-refresh-2026-07-01 | udu-design-table.xlsx | fabrication | V5 refresh provenance log-only pass: confirms visual-output-register.csv CAD-001 authority=fabrication (pre-existing OpenSCAD master-shape starter, unchanged this pass — see cad/udu_master.scad header for its own authority caveat). |
| 2026-07-01T00:00:00Z | claude-code (Fable 5) | packet_refresh | cad/sw-design-table.xlsx | fable-v5-refresh-2026-07-01 | family-spec.csv | fabrication | V5 refresh provenance log-only pass: confirms visual-output-register.csv DT-002 authority=fabrication; no dimension changes made. |

Future V5 promotion must append one row per actual MCP session and artifact before claiming MCP provenance coverage.

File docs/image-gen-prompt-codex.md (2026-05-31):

# Image Generation Prompts

Concept image only; not fabrication authority. Do not include cut-ready dimensions, hole locations, tuning charts, or toolpaths.

## Hero Prompt

Photorealistic 3/4 studio product photograph of a finished slip-cast ceramic udu drum, medium family member: rounded Cone-6 stoneware vessel body with a top mouth opening, one smooth side hole, softly rounded hand-contact rims, subtle foot pads or stable base area, and an exterior-only glaze that leaves the playable port edges comfortable and tactile. The object should read as a Nigerian clay vessel drum, not a generic vase: closed resonant body, playable mouth and side-hole geometry, warm ceramic surface, modest handmade variations, realistic tabletop-to-lap scale. Clean studio background, soft directional studio lighting, 50mm lens, high detail, photorealistic.

## In-Context Prompt

Photorealistic ceramic studio scene of the udu being played by hand on a low stand or lap-height cushion, one hand hovering over the top mouth and the other near the side hole for slap and pitch-sweep technique. Include plaster mold halves, a sealed 3D-printed master, leather-hard clay tools, and a kiln shelf in the environment as quiet production context. Natural window light, grounded workshop storytelling, respectful presentation of the instrument's Igbo lineage, no marketing logos.

## Detail Prompt

Photorealistic macro close-up of the udu side-hole and mouth area: smooth rounded ceramic side port edge, glazed exterior surface, slightly unglazed or satin playable rim, visible wall thickness impression without measurement marks, and subtle clay speckle from fired stoneware. Shallow depth of field, soft side light, high detail, tactile ceramic texture.

## Negative / Avoid

No text, labels, watermarks, brand marks, extra limbs, impossible holes, vase-only silhouette with no side port, fantasy tribal symbols, cutaway dimension callouts, DXF-like line art, or fabrication measurements; hands must be anatomically plausible if shown.

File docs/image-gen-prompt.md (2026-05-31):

# Image-Gen Prompts

Concept image only; not fabrication authority. Do not include cut-ready dimensions, hole locations, or toolpaths.

## Hero Prompt

A single slip-cast ceramic udu drum — a closed, full-bellied Nigerian clay vessel drum — photographed as a finished physical object on a clean neutral light-grey studio sweep. The body is a rounded, slightly egg-shaped stoneware pot that narrows to a short open neck and a circular mouth opening at the top; a single round side hole is cut into the swell of the belly, its rim smoothed and slightly flared for repeated hand slaps. Fired Cone-6 stoneware with a satin-matte glazed exterior in a warm earthen tone (clay-brown to dark slate), the rim of the mouth and the edge of the side hole left rounded and comfortable, the unglazed interior implied by the dark void inside the mouth. Subtle, gentle foot pads or a flattened base let it sit stably on the surface. Realistic tabletop scale — a vessel roughly the size of a large floor pot. Soft directional studio light from upper left, gentle falloff and a soft shadow, photorealistic, 3/4 product-photography angle, ~50mm lens, high detail, no text labels.

## In-Context Prompt

A ceramic udu drum staged in a percussionist's practice space or a ceramics studio, sitting on a low wooden stool or woven mat, warm natural window light raking across the glazed belly. A pair of relaxed, anatomically plausible hands hover near the mouth and the side hole as if mid-phrase — one palm poised to slap the side port, one fanning over the mouth to bend the pitch. Background softly out of focus: shelves with bisque pots, a kiln door, or stage curtains, telling the story of a fired ceramic instrument that is played by sealing and opening its two ports. Shallow depth of field, golden ambient light, concept visualization only, photorealistic, no text labels.

## Detail Prompt

Macro close-up of the udu's signature side hole — the round port cut into the swell of the stoneware belly — showing the smoothed, gently flared lip meant for repeated hand slaps, the satin glaze surface meeting the rounded port edge, and the dark unglazed interior receding into shadow beyond. Raking low-angle light reveals the subtle surface texture of fired stoneware, faint throwing-style undulation, and the crisp clean transition from glazed exterior to bare clay at the hole edge. Extremely high detail, shallow depth of field, no measurements, no text.

## Negative / Avoid

No text, logos, watermarks, or fake maker marks; no dimension callouts or measurement lines; no drumheads, skins, tension rods, or membrane-drum hardware; no impossible mechanisms; if hands are shown they must be anatomically plausible.

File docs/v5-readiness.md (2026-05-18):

# Udu V5 Readiness Notes

Current status: V5 explorer/readiness packet, not a full V5 build-packet candidate.

The repo already has a strong v4.1 baseline: a parametric workbook, `family-spec.csv`, an OpenSCAD master-shape starter, SolidWorks import references, SVG previews, concept imagery, a print packet, and a risk register. Those artifacts are enough to orient a builder and reviewer, but not enough to claim production-ready geometry or measured acoustic validation.

## Evidence That Currently Controls Dimensions

| Evidence | Path | Current authority |
| --- | --- | --- |
| Parametric workbook | `udu-design-table.xlsx` | Design-table authority for current assumptions. |
| Family rows | `family-spec.csv` | Planning authority with measurement-required acoustic caveats. |
| OpenSCAD starter | `cad/udu_master.scad` | Fabrication-geometry starter derived from the workbook, not final production CAD. |
| SolidWorks design table | `cad/sw-design-table.xlsx` | Import-table authority limited to current v4.1 assumptions. |

## Remaining V5 Gates

| Gate | Status | Evidence needed |
| --- | --- | --- |
| Parametric CAD | Partial | Existing OpenSCAD starter needs measured shrinkage, fired volume, rim radius, foot/stand geometry, and per-size port corrections. |
| Vector design plates | Partial | SVG previews exist; DXF exports are not present and must not be implied. |
| Hero render | Partial | Existing hero image is concept-only, not a Blender render from exported CAD/STL. |
| Exploded diagram | Missing | Needs a generated or drawn component-offset diagram from the CAD authority chain. |
| AI artistic shots | Partial | Concept images exist and are registered as non-authoritative. |
| Annotated print plate | Missing | Needs an assembly plate whose callouts cite design-table cells. |
| MCP provenance log | Partial | `cad/mcp-session-log.md` currently records that no MCP sessions were run in this lane. |

## Vessel-Resonator Caveats

The workbook uses first-order dual-port Helmholtz predictions. Real udu behavior also depends on player hand impedance, partial port coverage, fired chamber volume, port-edge radius, wall thickness after shrinkage, and glaze firing. `family-spec.csv` therefore records the acoustic law as `unknown_requires_measurement` for the V5 validator until physical prototype measurements can replace the current assumptions.

Do not promote the repo to measured, validated, L2/L3/L4, or production-ready status until fired prototype measurements and CAD/DXF/design-table updates are present.

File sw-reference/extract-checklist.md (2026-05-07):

# Extract_Dimensions.swp — Run Checklist

Before running the macro on `UDU-000_MasterLayout.SLDPRT`:

- [ ] Save the part. The macro reads in-memory state but file-save
      gives you a rollback point if the macro errors out.
- [ ] Activate the configuration you want to capture as the
      *primary* row. The macro walks all configurations regardless
      of which is active, but the active config drives the
      `AssemblyConfigName` field.
- [ ] Confirm `Tools > Options > External References > Search routing`
      points at the correct design-table xlsx — drift at this layer
      causes silent value mismatches.
- [ ] Note the date and active configuration in the macro output
      filename: `cad/dimensions/<date>-<config>.csv`.

## Running the macro

1. `Tools > Macro > Run > Extract_Dimensions.swp`
2. The macro shows a file-save dialog; save the CSV into
   `cad/dimensions/<date>-<active-config>.csv`.
3. Wait for the macro to finish. Expect ~5–15 seconds for a single-part
   model with 4 configurations.

## Verifying the output

- [ ] Open the CSV in Excel (or `csvlook < cad/dimensions/<file>.csv`
      from a shell). Row count should be approximately
      `(globals × configurations) + (feature dims × configurations)`.
      For the udu master with 14 globals and ~10 feature dimensions
      across 4 active configurations, expect ~96 rows.
- [ ] Spot-check that the `Value_in` column shows real inch values,
      not millimeter-converted approximations. (E.g., `body_diam_in`
      should read `10.0`, not `9.999...`.)
- [ ] Confirm the `IsGlobalVar` column has TRUE for the 14 globals
      and FALSE for the 10 feature dimensions.

## Diffing against the Excel design table

Once the CSV is captured:

```bash
python3 /path/to/skill/scripts/ingest_dimension_csv.py \
  --csv cad/dimensions/<date>-<config>.csv \
  --workbook udu-design-table.xlsx \
  --design-sheet Master_Inputs \
  --tolerance-percent 0.5 \
  --report sw-reference/drift-<date>.md
```

The report flags:
- **Match** — value equal within tolerance.
- **SW-only** — dimension in the SW model that doesn't appear in the
  Excel design table.
- **Excel-only** — dimension in Excel that the SW model doesn't have.
- **Mismatch** — both sides have it but values disagree.

A clean run reports zero issues. Anything else escalates to Tony for
manual reconciliation.

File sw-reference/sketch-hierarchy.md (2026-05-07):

# UDU-000_MasterLayout — Sketch Hierarchy

The udu master sketch follows the v4.1 SW convention: the master sketch
sits on the Front plane and contains the *driving* dimensions for the
body envelope. Other sketches reference it via `Convert Entities` or
`Pierce` relations. This keeps the dependency graph clean and lets the
design table propagate changes through one root.

```
Sketch_Master_Profile (root, Front plane)
  ├─ body_diam_in          (driving Ø)
  ├─ body_height_in        (driving height)
  ├─ shape_factor           (controls ovoid pinch)
  └─ wall_thk_in            (offset for inner profile)
        │
        ├── Reference plane: Mouth_Plane (top of body, normal to revolve axis)
        │     │
        │     └── Sketch_Mouth_Port (pierces master, references mouth_diam_in)
        │
        ├── Reference plane: Side_Hole_Plane (mid-height, hand-comfort offset)
        │     │
        │     └── Sketch_Side_Port (pierces master, references side_diam_in)
        │
        └── Sketch_Inner_Profile (offset Sketch_Master_Profile by wall_thk_in)
              │
              └── (used to subtract chamber from solid revolve)
```

## Feature order

```
1. Sketch_Master_Profile          (master ovoid outline)
2. Revolve1                       (creates outer body solid)
3. Sketch_Inner_Profile           (offset inward for chamber)
4. Revolve2 (cut)                 (subtracts chamber → hollow body)
5. Sketch_Mouth_Port (extrude cut) (top opening)
6. Sketch_Side_Port (extrude cut)  (side hand-slap port)
7. Fillet1                        (rim radius ≥ 1/8" — see risks.md ERG-02)
8. Fillet2                        (side-hole edge radius)
```

## What NOT to do

- **No raw numeric dimensions** in any feature. Every dimension must
  reference a global (`body_diam_in`, `mouth_diam_in`, etc.) or an
  arithmetic combination of globals.
- **No sketches that bypass the master profile.** The mouth port and
  side port both `Pierce` `Sketch_Master_Profile`. If a new feature
  needs the ovoid outline, it references the master sketch — it does
  not redraw it.
- **No hand-tuned shrinkage compensation in the SW model.** The fired
  geometry is what's modeled. Master scaling is applied at STL export
  via `master_scale_factor` (a single multiplier on all dimensions),
  not by editing each dimension.

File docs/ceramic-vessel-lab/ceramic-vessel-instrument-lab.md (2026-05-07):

# Ceramic Vessel Instrument Lab

This folder turns the existing `Ocarina.xlsx` and `Udu.xlsx` design tables into shop-facing build packets, then extends the same Helmholtz-resonator logic into a new vessel-flute research track.

## Source Files

| Instrument | Live design table | Build packet |
| --- | --- | --- |
| Ocarina | `docs/Ocarina.xlsx` | `docs/build-packets/ocarina/` |
| Udu drum family | `docs/Udu.xlsx` | `docs/build-packets/udu-drum-family/` |
| Experimental vessel flutes | TBD design table | `docs/build-packets/vessel-flute-lab/` |

## Program Goal

Use slip casting and 3D-printed mold masters to create repeatable ceramic vessel instruments whose pitch, response, and timbre can be tuned through measured cavity volume, wall thickness, voicing geometry, hole area, and firing shrinkage.

This is a good first ceramic instrument program because the udu, ocarina, water whistle, and sculptural vessel flute all share the same governing model:

```text
f = c/(2*pi) * sqrt(A_open/(V_chamber * L_eff))
```

The interesting part is not just hitting a note. It is learning how fired ceramic moves the model:

- Clay shrinkage changes volume, openings, and wall thickness.
- Wall thickness affects shell tap tone, projection, weight, and drying risk.
- Glaze changes mass, edge sharpness, and hole size.
- Mold drainage time controls cast wall thickness.
- Fipple and labium geometry often dominate playability more than the chamber formula.

## Recommended Build Order

1. **Small udu** - Fastest validation of slip-cast chamber volume, wall thickness, and two-port Helmholtz behavior.
2. **Alto C ocarina test body** - Adds fipple voicing and multi-hole tuning without requiring long straight bores.
3. **Water whistle / bird vessel** - Same physics with water-variable volume and sculptural freedom.
4. **Experimental vessel flute series** - Organic forms, multiple chambers, drone vents, and unusual hand layouts.
5. **Ceramic body electric violin** - Move here after mold repeatability, structural inserts, and firing distortion are under control.

## Shared Measurement Protocol

Every prototype should get a build number and the same measurements:

| Stage | Measurements |
| --- | --- |
| CAD master | Target chamber volume, target opening diameters, wall target, scale factor for shrinkage |
| Printed master | Measured master dimensions, print material, sealant, surface finish |
| Plaster mold | Mold weight, dry time, number of pours, registration quality |
| Green cast | Pour time, drain time, wall thickness sample, leather-hard mass, hole diameters |
| Bone dry | Mass, visible cracks/warps, chamber volume if measurable |
| Bisque | Mass, dimensions, volume, open-hole frequencies, fipple response |
| Glaze fired | Final mass, dimensions, volume, frequencies, cents error, tuning changes |

## Key Research Questions

- How close does the Helmholtz model predict greenware, bisque, and glaze-fired frequencies?
- Does stoneware or porcelain give better voicing stability for small fipple instruments?
- How much does exterior-only glaze shift ocarina/vessel-flute pitch?
- What wall thickness gives the best balance between durability and lively ceramic tap tone?
- Can 3D printed masters create vessel shapes that are hard to hand-build but still mold-release cleanly?
- Can non-round, organic chambers be reduced to measured water volume for reliable tuning?
- Can a vessel flute combine a Native American style breath feel with ocarina-style pitch control?

## Documentation To Keep Together

Each build packet uses this structure:

- `design.md` - source table, model, design intent, assumptions, and next improvements.
- `bom.csv` - material and tool list with workbook estimates where available.
- `sourcing.csv` - supplier/search-term fields without claiming current availability.
- `validation.csv` - tuning, shrinkage, wall-thickness, and build-result log.
- `assembly-manual.md` - shop workflow from CAD master through final tuning.
- `drawing-brief.md` - what the manufacturable drawing or CAD package must show.
- `visual-bom-brief.md` - image/BOM plate direction for future documentation.
- `wolfram-starter.wl` - notebook starter for physics exploration.

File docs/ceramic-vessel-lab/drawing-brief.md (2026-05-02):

# Udu Drum Family Drawing Brief

## Required Views

- Front view with overall height, max body diameter, mouth diameter, and side-hole position.
- Side view showing body profile, wall target, side-hole axis, and foot/stand contact.
- Top view showing mouth opening, rim radius, and symmetry datums.
- Section view through mouth and side hole showing wall thickness and effective neck length.
- Mold split view with registration keys, plaster thickness, pour/drain direction, and seam-cleanup zone.
- Optional electric variant view showing piezo location, wire path, jack location, and service access.

## Critical Dimensions

| Dimension | Source | Tolerance intent |
| --- | --- | --- |
| Chamber volume | Workbook formula and water-fill measurement | Tuning critical |
| Body diameter and height | Workbook inputs | Tuning and ergonomics |
| Mouth diameter | Workbook input | Tuning and hand seal |
| Side-hole diameter | Workbook input and tuning log | Tuning and playability |
| Wall thickness | Workbook input and cast measurement | Tap tone/durability |
| Rim radii | CAD and ergonomic test | Comfort |
| Master scale factor | Measured clay shrinkage | Process critical |

## Notes For CAD

- Use a named shape factor or profile parameter so S/M/L/XL can be regenerated from the same model.
- Keep side-hole position as a parameter tied to hand comfort, not only aesthetics.
- Design any feet as optional variants so acoustic damping can be tested.
- Keep the water-udu variant separate because water fill and leak-tightness change requirements.

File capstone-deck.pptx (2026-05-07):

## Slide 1

Slip-Cast Ceramic Udu Drum Family — v4.1 Capstone

Musical instrument documentation capstone
Build packet: udu
Generated: 2026-05-07

Slip-Cast Ceramic Udu Drum Family — v4.1 Capstone | Slide 1 of 15

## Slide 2

Project Intent

• Build a slip-cast ceramic udu family — Small / Medium / Large / XL — with
repeatable chamber volumes and two playable Helmholtz tones: the main mouth
tone and the side-hole slap tone. The first production target is the
**Medium** standard udu (UDU-P2: 10 in × 12 in body, B3 mouth / G3 side),
followed by a scaled family. The udu (Igbo: *ụdụ*, "vessel") is a Nigerian
clay-vessel drum and the documentation here treats that lineage as fact, not
marketing.

Slip-Cast Ceramic Udu Drum Family — v4.1 Capstone | Slide 2 of 15

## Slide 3

Physics Model

• The udu uses a shared chamber with two coupled Helmholtz resonators:
f_top = c/(2*pi) * sqrt( A_top / (V * L_top) )
f_side = c/(2*pi) * sqrt( A_side / (V * L_side) )
L = wall_thickness + 0.6 * sqrt(A/pi)
V = (pi/6) * body_diam^2 * body_height * shape_factor

Slip-Cast Ceramic Udu Drum Family — v4.1 Capstone | Slide 3 of 15

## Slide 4

Hardware Alignment

• This repo is one of the slip-cast targets for the in-flight Bambu printer +
ceramic kiln pipeline shared with `ocarina/`, `gemshorn/`, and
`transverse-flute/`. The build chain:

Stage | Tool / pipeline | Notes
Design table | `udu-design-table.xlsx` Master_Inputs | Blue cells = inputs; volume formula derived
Master scaling | `master_scale_factor = 1/(1 - measured_shrinkage)` | Re-derive per slip batch — see risks.md SUP-01
Master print | Bambu X1C (UDU-S, UDU-M) or outsourced print (UDU-L, UDU-XL) | X1C envelope ≈ 256 mm; L/XL exceed it — see risks.md SUP-02
Mold | Two-piece plaster mother mold, USG #1 pottery plaster | Split line off the hand-contact equator
Cast | Cone 6 stoneware casting slip | Shrinkage coupon required per batch
Trim | Side hole cut at leather-hard, undersized | Final tune at bisque
Fire | Cone 06 bisque → Cone 6 glaze | Glaze exterior only
Validate | `validation.csv` mouth/side/coupled measurements | `record_measurement.py` updates per-family corrections
CAD round-trip | `UDU-000_MasterLayout.SLDPRT` ↔ `cad/sw-design-table.xlsx` | See `sw-reference/` for the SW workflow

Slip-Cast Ceramic Udu Drum Family — v4.1 Capstone | Slide 4 of 15

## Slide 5

How To Use This Packet

• Start with design.md for intent and assumptions.
• Use bom.csv, sourcing.csv, and cut-list.csv before buying or cutting.
• Use drawing-brief.md and CAD/CNC folders before machining.
• Print the packet for shopping, shop work, and validation.

Slip-Cast Ceramic Udu Drum Family — v4.1 Capstone | Slide 5 of 15

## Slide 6

File Map

• design.md: Project intent, catalog metadata, assumptions, and validation plan.
• bom.csv: Starter bill of materials with part categories, quantities, drawing refs, and notes.
• sourcing.csv: Supplier/search tracker with specs, price/date fields, lead time, substitutes, and risks.
• cut-list.csv: Rough/final stock sizes, material, grain/orientation, operations, yield, and offcuts.
• drawing-brief.md: Manufacturing drawing and technical product sketch brief.
• assembly-manual.md: Shop-facing sequence, tools, fixtures, safety, tuning, finishing, and maintenance notes.
• validation.csv: Target/measured values, tolerance, environment, result, and tuning/build action log.
• supplier-rfq.md: Supplier email/request-for-quote starter.

Slip-Cast Ceramic Udu Drum Family — v4.1 Capstone | Slide 6 of 15

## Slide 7

Family Spec

member_id | target_note_mouth | target_hz_mouth | target_note_side | target_hz_side | body_diam_in | body_height_in | wall_thk_in | mouth_diam_in | side_diam_in | shape_factor | chamber_volume_cuin | predicted_hz_mouth | predicted_hz_side | cents_error_mouth | cents_error_side | master_scale_factor | clay_body | shrinkage_pct | reference_repo | notes
UDU-S | D#4 | 311.13 | A3 | 220.00 | 8.0 | 10.0 | 0.30 | 3.0 | 2.0 | 0.70 | 234.6 | 340.8 | 262.4 | +157 | +304 | 1.136 | Cone 6 stoneware | 12 | udu | Small/tabletop. Predictions sharp of targets — mouth dia likely needs to drop ~2.5 in OR shape factor increased to reduce predicted Hz; flag for empirical UDU-P1 measurement.
UDU-M | B3 | 246.94 | G3 | 196.00 | 10.0 | 12.0 | 0.30 | 3.0 | 2.0 | 0.70 | 439.8 | 248.9 | 191.6 | +14 | -39 | 1.136 | Cone 6 stoneware | 12 | udu | Medium/standard. Workbook prototype-1 target. Predictions within ±50¢ of targets — hits the v4 design-table band.
UDU-L | G#3 | 207.65 | D3 | 146.83 | 12.0 | 14.0 | 0.30 | 3.0 | 2.0 | 0.70 | 738.8 | 192.1 | 148.0 | -126 | +14 | 1.136 | Cone 6 stoneware | 12 | udu | Large/deep bass. Mouth prediction flat of target — port may need to enlarge slightly OR shape factor reduced; flag for empirical UDU-L measurement.
UDU-XL | F3 | 174.61 | C3 | 130.81 | 14.0 | 16.0 | 0.30 | 3.0 | 2.0 | 0.70 | 1148.7 | 153.9 | 118.5 | -220 | -172 | 1.136 | Cone 6 stoneware | 12 | udu | Concert bass. Predictions flat across both ports — XL may need port scaling (mouth 3.5+ in) to recover pitch; needs stand. Flag as design risk — see risks.md.

Slip-Cast Ceramic Udu Drum Family — v4.1 Capstone | Slide 7 of 15

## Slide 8

Build Workflow

• Design and assumptions
• Source materials and hardware
• Prepare stock, fixtures, and CNC/laser/lathe setup
• Assemble, tune, finish, and validate

Slip-Cast Ceramic Udu Drum Family — v4.1 Capstone | Slide 8 of 15

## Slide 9

Sourcing And BOM

• BOM gives part categories and drawing references.
• Sourcing tracks search terms, supplier candidates, price/date, lead time, substitutions.
• Visual BOM brief turns the parts list into a presentation-ready image board.

Slip-Cast Ceramic Udu Drum Family — v4.1 Capstone | Slide 9 of 15

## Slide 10

Shop Packet

• Cut list for lumber/sheet/blank planning.
• Assembly manual for away-from-keyboard work.
• Validation sheet for measured dimensions, tuning, pass/fail checks.

Slip-Cast Ceramic Udu Drum Family — v4.1 Capstone | Slide 10 of 15

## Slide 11

Drawings, CAD, CNC

• drawing-brief.md defines required views, dimensions, datums, sketch intent.
• cad/ holds models and design tables.
• cnc/ holds CAM, toolpaths, setup sheets, dry-run notes.
• drawings/ holds PDFs, SVGs, DXFs, drawing exports.

Slip-Cast Ceramic Udu Drum Family — v4.1 Capstone | Slide 11 of 15

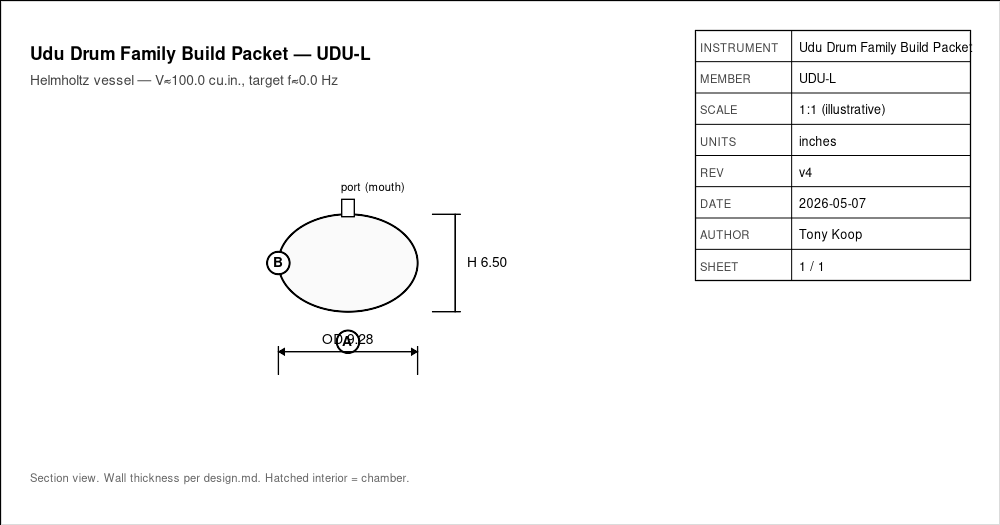
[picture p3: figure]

UDU-L-body.png

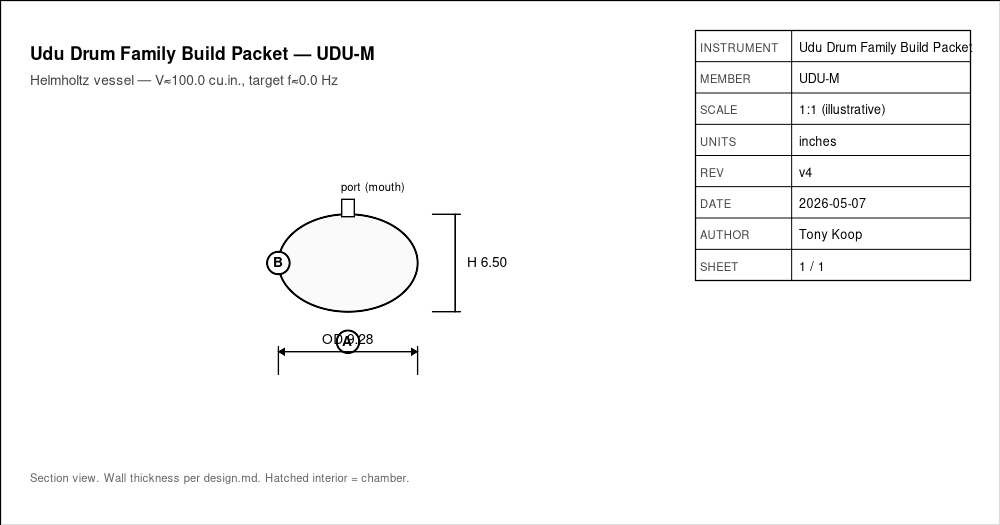
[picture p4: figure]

UDU-M-body.png

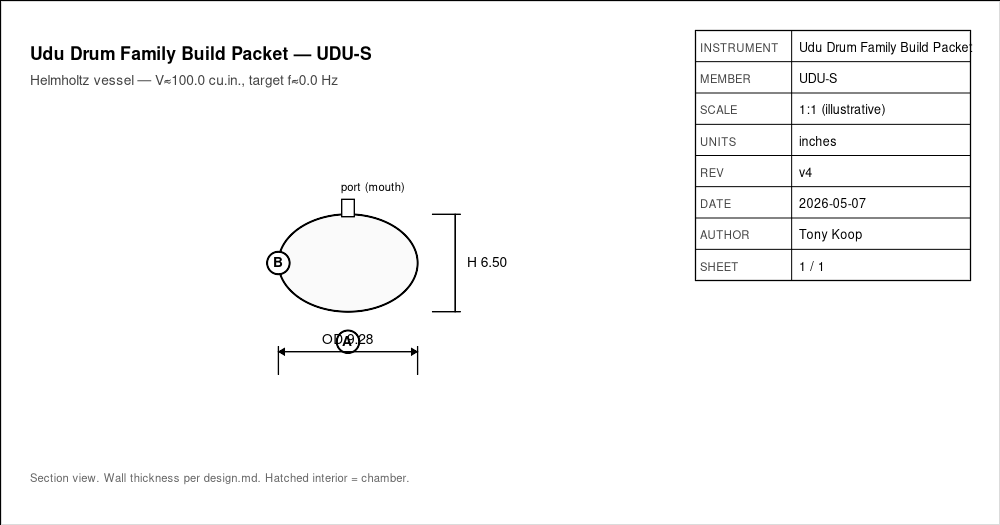
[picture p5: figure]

UDU-S-body.png

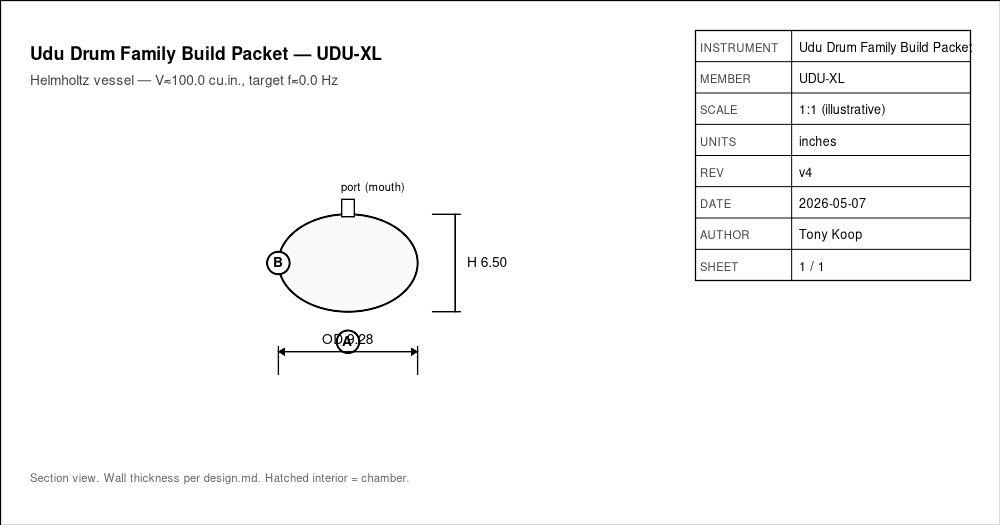
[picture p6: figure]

UDU-XL-body.png

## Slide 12

Images And Screenshots

• images/family-overview-concept.png
• images/family-overview-concept.svg
• images/hero-concept.png
• images/hero-concept.svg

Slip-Cast Ceramic Udu Drum Family — v4.1 Capstone | Slide 12 of 15


family-overview-concept.png

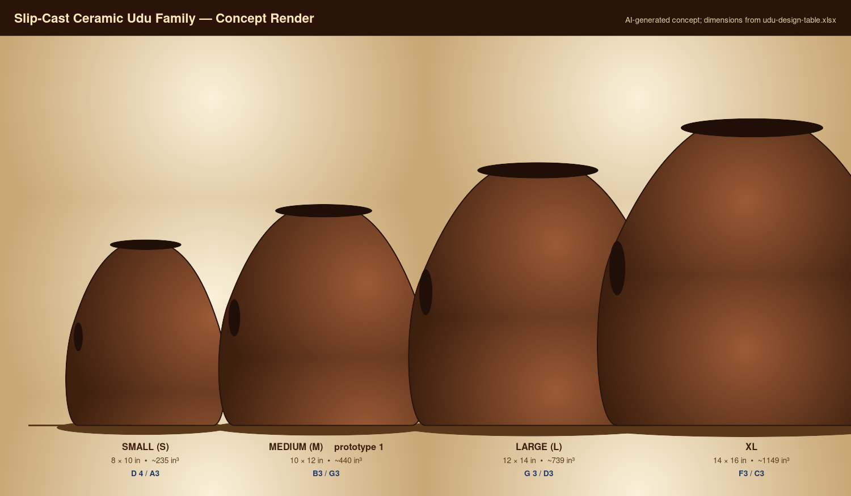
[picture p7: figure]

family-overview-concept.png


hero-concept.png

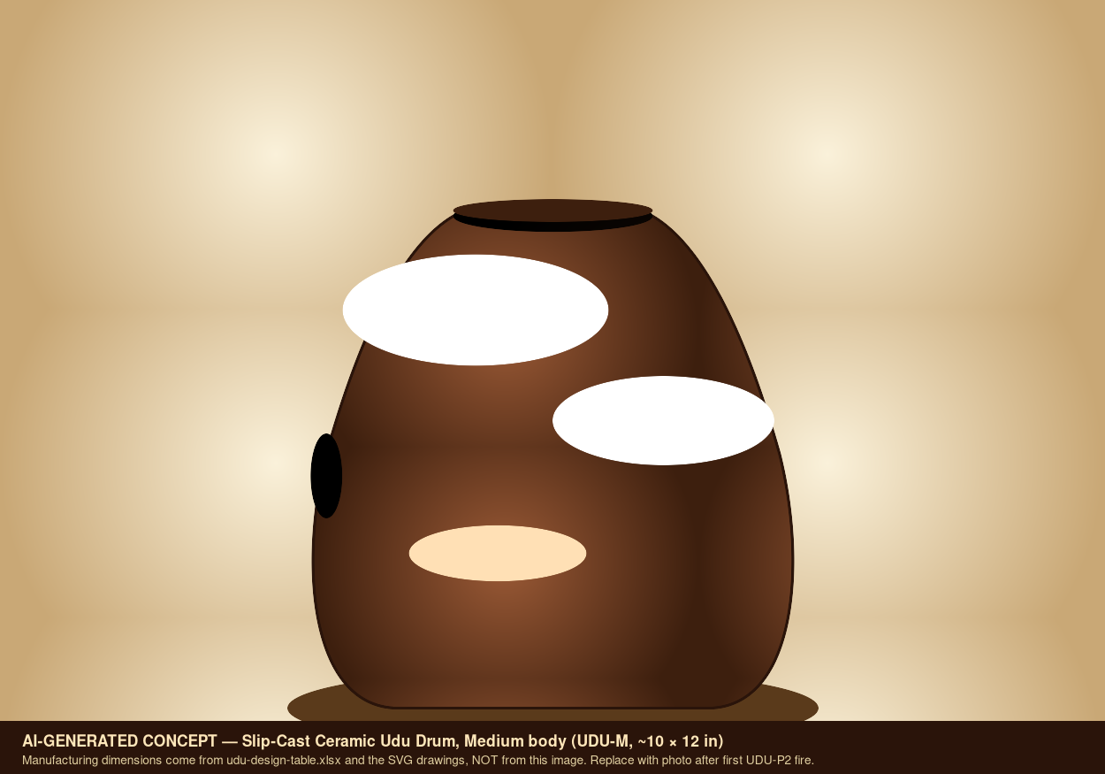
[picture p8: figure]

hero-concept.png

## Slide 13

Validation Plan

• A4 = 440 Hz reference check.
• Tuning targets logged in validation.csv.
• Critical dimensions verified against design sheet and CAD.
• Photos and revision notes after each major step.

Slip-Cast Ceramic Udu Drum Family — v4.1 Capstone | Slide 13 of 15

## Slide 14

Open Risks / Decisions

• TBDs in design sheet and BOM.
• Supplier price/availability not yet verified.
• Generated images marked as concept placeholders.
• Empirical corrections await measured prototype data.

Slip-Cast Ceramic Udu Drum Family — v4.1 Capstone | Slide 14 of 15

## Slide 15

Next Actions

• Replace TBDs with measured/source-backed values.
• Verify live supplier price and availability before buying.
• Export final drawings and visual BOM images.
• Regenerate this deck and print packet after final edits.

Slip-Cast Ceramic Udu Drum Family — v4.1 Capstone | Slide 15 of 15

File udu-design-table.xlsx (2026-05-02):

Udu Drum Family — Dual Helmholtz Ceramic Pot Drum
Nigerian Igbo tradition · Slip cast or wheel thrown · Two openings = two Helmholtz bass tones · Idiophone + Aerophone hybrid
DESIGN INPUTS — Medium (Standard) Udu
Body Diameter (in) | 10.0 | ← Ovoid body widest point
Body Height (in) | 12.0
Wall Thickness (in) | 0.30 | ← ~7-8mm; thicker = brighter tap, less bass
Mouth Diameter (in) | 3.0 | ← Top opening; larger = higher Helmholtz tone
Side Hole Diameter (in) | 2.0 | ← Slap hole; smaller = deeper bass pulse
Shape Factor | 0.70 | ← 0.5=elongated, 0.7=ovoid, 0.9=spherical
Clay Body | Cone 6 Stoneware
Shrinkage % | 12% | ← Build oversized; shrinks to target after firing
Speed of Sound (in/s) | 13510 | ← Air at ~68°F (20°C)
DUAL HELMHOLTZ RESONANCE — f = (c/2π) × √(A / (V × L_eff))
Body Volume (in³) |  | ← = π/6 × D² × H × shape_factor
Mouth Area (in²)
Mouth L_eff (in) |  | ← wall + end correction
Mouth Helmholtz Freq (Hz)
Mouth Nearest Note
Side Hole Area (in²)
Side Hole L_eff (in)
Side Hole Helmholtz Freq (Hz)
Side Hole Nearest Note
Interval (semitones) |  | ← Mouth is higher pitch; positive = mouth above side hole
UDU FAMILY — 4 Sizes + 2 Variants
Model | Diam (in) | Height (in) | Vol (in³) | Mouth Hz | Side Hz | Bass Range | Best For
Small (tabla-style) | 8 | 10 | 235 | D#4 (311) | A3 (223) | A3–D#4 | Tabletop, small venues, high tones
Medium (standard) ⭐ | 10 | 12 | 440 | B3 (249) | G3 (192) | G3–B3 | Most versatile; the classic Udu size
Large (Nigerian) | 12 | 14 | 739 | G#3 (207) | D3 (144) | D3–G#3 | Deep bass; traditional ceremonial size
XL (concert bass) | 14 | 16 | 1149 | F3 (178) | C3 (131) | C3–F3 | Sub-bass; orchestra/studio, needs stand
VARIANTS
Utar (dual-chamber) | Two connected pots | Narrow neck joins two chambers | Two different Helmholtz tones per chamber | F#3 + D4 (large)
Kim Kim (side hole) | Spherical, side hole only | No neck; just a round pot | Simpler form, one dominant bass tone | Igbo ceremonial
Claytone (LP style) | Elongated with long neck | 14" tall, neck adds overtones | Commercial; chrome/terracotta glaze | LP Percussion
Udongo (Kenyan) | Gourd-shaped | Wider bottom, narrow top | More body tap tones from thin walls | East African
Water Udu | Partially water-filled | Water changes volume = pitch bend | Pitch shifts as you tilt — like a talking drum | Iranian Kuzeh
PLAYING TECHNIQUES — 5 Distinct Sounds from One Instrument
Technique | Action | Sound | Physics | Pitch Range
1. Mouth Slap (bass) | Cup palm over mouth, slap and seal | Deep "doom" — the signature Udu bass | Helmholtz resonance of full cavity via mouth | B3 (formula-calculated)
2. Side Hole Pop | Slap side hole with cupped hand, release | "Plop" or "whoop" — pitch bends on release | Helmholtz via smaller side opening | G3 (formula-calculated)
3. Body Tap (ceramic) | Tap body surface with fingertips or knuckles | Bright "tick" or "tock" — like a woodblock | Shell vibration (idiophone); thinner wall = louder | High (500-2000 Hz)
4. Mouth Wah | Slap mouth then slowly open/close hand | Pitch bends up as hand opens — "wah-wah" | Changing effective neck area in real time | G3→B3 sweep
5. Rim Roll | Roll fingers rapidly around mouth rim | Sustained resonant hum | Exciting Helmholtz mode continuously | At Helmholtz freq
CERAMIC PRODUCTION — Slip Cast or Wheel Thrown
# | Method | Pros | Cons | Tony Feasibility
A | Slip Casting (3D print master → plaster mold) | Repeatable volume = consistent pitch; production scale | 2-piece mold needed; seam to finish; setup investment | ⭐ Best for family production
B | Wheel Throwing (traditional) | Authentic; unique each piece; no mold needed | Volume varies = pitch varies; skill intensive | ✅ If you have wheel access
C | Press Molding (2-part plaster) | Faster than slip; good volume control | Slab thickness harder to control vs slip | ✅ Good middle ground
D | Coil Building (hand) | No equipment; most artistic freedom | Slowest; least repeatable; cracks at coil joins | ⚠️ For one-offs only
SLIP CAST WORKFLOW (recommended for Udu family)
1. CAD the Udu profile in SolidWorks (use design inputs above; scale UP by 1/(1-shrinkage))
2. 3D print the master positive (2 halves split at equator, alignment pins)
3. Build plaster cottle (box) around each half, pour #1 Pottery Plaster, cure 24-48 hrs
4. Remove 3D print, dry mold 5-7 days. Mold = 2 halves that clamp together
5. Pour slip into assembled mold. Drain after target wall thickness builds (~7mm = 15-20 min)
6. Demold when leather-hard (~2 hrs). Clean seam with sponge + rib
7. Cut side hole with hole cutter while leather-hard. Smooth edges
8. Dry slowly (1-2 weeks under plastic, then uncovered). NO cracks allowed
9. Bisque fire to Cone 06 (~1830F). Test pitch — this is your tuning checkpoint
10. Tune: enlarge side hole to LOWER the Helmholtz bass (careful! can only remove material)
11. Glaze exterior (leave inside unglazed for better resonance). Fire to Cone 6 (2230F)
12. Final pitch check — glaze adds mass + stiffness, may shift pitch slightly
BILL OF MATERIALS
# | Item | Qty | Spec | Est. Cost
1 | Casting slip (Cone 6 stoneware) | 5 gal | Commercial premixed; enough for 8-12 medium Udus | $35-50
2 | #1 Pottery Plaster | 50 lbs | For 2-part mold; 1 bag makes ~4 mold sets | $25-35
3 | 3D printed master (PLA) | 2 halves | Scaled up by 1/(1-shrinkage); FDM fine, sand smooth | $5-15
4 | Mold soap / release agent | 1 bottle | Murphy's Oil Soap or commercial mold soap | $8-12
5 | Hole cutter set | 1 set | 1.5", 2", 2.5", 3" round cutters for leather-hard clay | $10-20
6 | Kiln firing (per load) | 2 fires | Bisque Cone 06 + Glaze Cone 6; community kiln or own | $20-50/fire
7 | Glaze (exterior) | 1 pint | Cone 6; matte earth tones recommended for authentic look | $10-20
8 | Rubber feet (set of 3) | 1 set | Self-adhesive; prevents sliding and dampens bottom | $3-5
9 | Contact pickup (optional) | 1 | Piezo disc; epoxy to inside wall near side hole | $15-30
 | STARTUP TOTAL (mold + materials) |  |  | $131-247
 | PER UDU (after mold is made) | ← Sell at $60-150 each |  | $8-20
DESIGN NOTES
1. VOLUME CONTROLS PITCH. A 10% volume increase lowers the Helmholtz frequency by ~5%. This is why slip casting (consistent volume) beats wheel throwing for tuned sets.
2. SIDE HOLE SIZE is your primary tuning control after firing. Enlarging it LOWERS the bass tone (counterintuitive: bigger hole = lower pitch because L_eff changes dominate at small sizes).
3. WALL THICKNESS affects tap tone (idiophone) but NOT Helmholtz pitch. Thinner walls = louder tap + more fragile. 6-8mm is the sweet spot.
4. LEAVE INSIDE UNGLAZED. Glaze dampens the interior reflections that give the Udu its rich overtones. Glaze exterior only for durability.
5. SHRINKAGE MATTERS. A 12% shrinkage clay means your mold master must be 1/(1-0.12) = 1.136x oversize. CAD this into the 3D print.
6. FOR A TUNED FAMILY (4 sizes): build all 4 molds from the same master, scaled parametrically in SolidWorks. One design table drives all sizes.
7. THE WATER UDU is the most fascinating variant. Add water through the mouth; as you tilt, the water shifts = volume changes = pitch bends in real time. Like a liquid talking drum.
8. ART FAIR PRICING: Small $60, Medium $85, Large $120, XL $150. A family of 4 displayed together = $415. Material cost ~$50 total = massive margin.
9. ELECTRIC OPTION: Epoxy a piezo disc to the inside wall near the side hole. Amplified Udu sounds incredible through a bass amp or PA with reverb.
10. CROSS-REFERENCE: Same Helmholtz formula as your Ocarina, Handpan Gu, Cajón, and Resonant Box sheets. The Udu is the purest application of this physics.
11. UTAR BUILD: For the dual-chamber variant, throw or cast two pots of different sizes and join at the mouths with slip while leather-hard. The neck between them is the coupling port.
12. CULTURAL NOTE: The Udu is sacred in Igbo tradition — the deep tones represent ancestral voices. Approach this instrument with respect for its origins.
WOLFRAM CLOUD NOTEBOOK SPEC — UDU DRUM FAMILY
Igbo (Nigeria) ceramic pot drum — DUAL Helmholtz (top hole + side hole) gives 2 distinct tones.
§1 — Origin & Etymology
Origin: Igbo people of southeastern Nigeria. Traditionally water jar repurposed as drum by women (sacred-instrument lineage).
Udu' Igbo for 'pot/vessel'. Cousins: kim kim (smaller), ibo drum, udongo (larger).
Wolfram items: GeoGraphics Igboland (SE Nigeria); TimelinePlot[{ancient pot drums, 1965 Frank Giorgini popularization, modern artisan studios}].
§2 — Physics
Dual Helmholtz: top hole + side hole share the same chamber → two coupled Helmholtz modes.
Top mode: f1 = (c/2π)·√(A_top/(V·L_top)). Side mode similar.
Coupling: when both open, modes split; when side covered/uncovered by hand, pitch jumps audibly — playing technique exploits this for 'wet' pitch bends.
Wolfram functions: 2-resonator Helmholtz coupled-mode analysis; Eigensystem for the 2×2 system.
§3 — Geometry & Materials
4 sizes (S/M/L/XL) + 5 variants (Utar, Kim Kim, Claytone, Udongo, Water udu). Slip-cast porcelain or stoneware.
Top hole ~30–60 mm; side hole ~20–40 mm. Volume varies by size.
Wolfram items: Manipulate top_A, side_A, V → coupled-mode frequencies; ParametricPlot3D pot shape.
§4 — Animations
Hand-on-side-hole Animate: cover/uncover side → see pitch jump in real time.
Coupled-mode visualizer: in-phase vs out-of-phase oscillation.
§5 — Executable Cells
fHelm[A_,V_,L_]:=(343/(2 π)) Sqrt[A/(V L)]
coupledUdu[A1_,A2_,V_,L1_,L2_]:= Eigenvalues[ matrix ]^(1/2)
uduSizes := {{small, V_S}, {medium, V_M}, {large, V_L}, {xl, V_XL}}
§6 — Wolfram Functions
Eigensystem, Manipulate, Animate, FindRoot, Periodogram, CloudDeploy, FormFunction.
WOLFRAM EXPLORATIONS — UDU DRUM FAMILY
Roadmap-inspired notebook ideas mapped to this instrument.
Coupled Helmholtz
→ Helmholtz Tuner + Coupled Oscillator (roadmap)
DUAL Helmholtz: top hole + side hole share chamber. 2x2 eigenvalue analysis gives mode split as a function of A_top/A_side. Animate hand covering side-hole → mode collapse → pitch jump.
5 variants compared (Utar, Kim Kim, Claytone, Udongo, Water): plot mode-split landscape; predict which variant has biggest 'wet' bend.
Manufacturing
→ Parametric → STL + Shrinkage Comp (roadmap)
Pot shape parametric. Account for 12% slip-cast shrinkage in master STL. Vary pot proportions to hit target tuning.
Cultural
→ World Atlas (roadmap)
Map Igboland + diaspora; phylogeny of pot drums (water jar instruments worldwide).

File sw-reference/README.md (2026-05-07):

# SolidWorks Reference — Udu Drum Family

Per-instrument SW reference folder for the udu packet. This mirrors the
convention from `drone-flutes/sw-reference/`, `tongue-drum/sw-reference/`,
and the rest of Tony's instrument repos: each instrument gets a small
folder that captures the SW MasterLayout convention, the global-equation
list, and the import procedure for the design table.

## Contents

| File | Purpose |
|---|---|
| `MasterLayout-equations.txt` | The global-equation list to paste into `Tools > Equations > Manage Equations` for `UDU-000_MasterLayout` |
| `import-design-table.md` | Step-by-step procedure for importing `../cad/sw-design-table.xlsx` as the embedded SW design table |
| `sketch-hierarchy.md` | The master-sketch dependency graph for the udu body |
| `extract-checklist.md` | What to verify before/after running `Extract_Dimensions.swp` |

## The Udu MasterLayout convention

The udu uses a **single master part** (`UDU-000_MasterLayout.SLDPRT`)
with four configurations driven by `cad/sw-design-table.xlsx`:

| Configuration | Member | Body Ø | Body H | Mouth Ø | Side Ø |
|---|---|---|---|---|---|
| `MASTER_TEMPLATE` | reference template | 10 in | 12 in | 3 in | 2 in |
| `UDU-S` | Small | 8 in | 10 in | 3 in | 2 in |
| `UDU-M` | Medium *(prototype 1)* | 10 in | 12 in | 3 in | 2 in |
| `UDU-L` | Large | 12 in | 14 in | 3 in | 2 in |
| `UDU-XL` | XL concert bass | 14 in | 16 in | 3 in | 2 in |

The 14 globals promoted into the design table from `family-spec.csv`:

```
target_hz_mouth     target_hz_side
body_diam_in        body_height_in        wall_thk_in
mouth_diam_in       side_diam_in
shape_factor        chamber_volume_cuin
predicted_hz_mouth  predicted_hz_side
cents_error_mouth   cents_error_side
master_scale_factor
```

## Round-trip workflow (Excel ↔ SolidWorks)

```
family-spec.csv
      │
      ▼
generate_sw_design_table.py  ──►  cad/sw-design-table.xlsx
                                              │
                                              │ (Insert > Tables > Design Table > From Existing File)
                                              ▼
                                  UDU-000_MasterLayout.SLDPRT
                                  (4 configurations)
                                              │
                                              │ (Run Extract_Dimensions.swp)
                                              ▼
                          cad/dimensions/<date>-<config>.csv
                                              │
                                              │ (ingest_dimension_csv.py)
                                              ▼
                                   findings report (drift report)
```

The contract: `family-spec.csv` is the single source of truth. The Excel
design table and the SW design table are both *views* of it. When Tony
edits a dimension in SW directly, run `Extract_Dimensions.swp` and then
`ingest_dimension_csv.py` to detect drift and update `family-spec.csv`.

See `references/solidworks-integration.md` in the instrument-maker-v4
skill for the canonical doc.

## Pack-and-Go derivation

Once the udu MasterLayout is stable, downstream instruments in the
slip-cast vessel-drum family can be derived via SW Pack-and-Go:

```
UDU-000_MasterLayout.SLDPRT
       │
       ├── Pack-and-Go ──► JEMBE-000_MasterLayout (skin-drum hybrid)
       └── Pack-and-Go ──► WATER-UDU-000_MasterLayout (UDU-P3 variant)
```

This is the same pattern used for `fujara → moseno` in the open-pipe family.

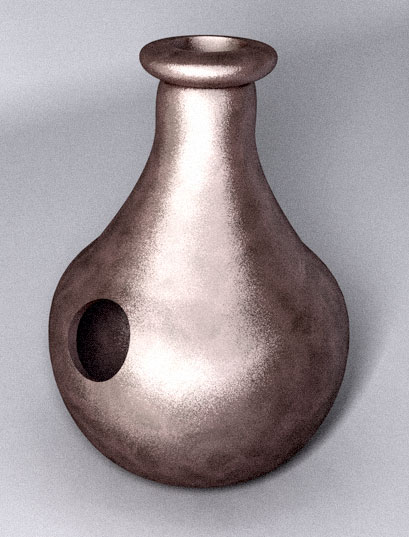
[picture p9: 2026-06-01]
images/hero-render.png

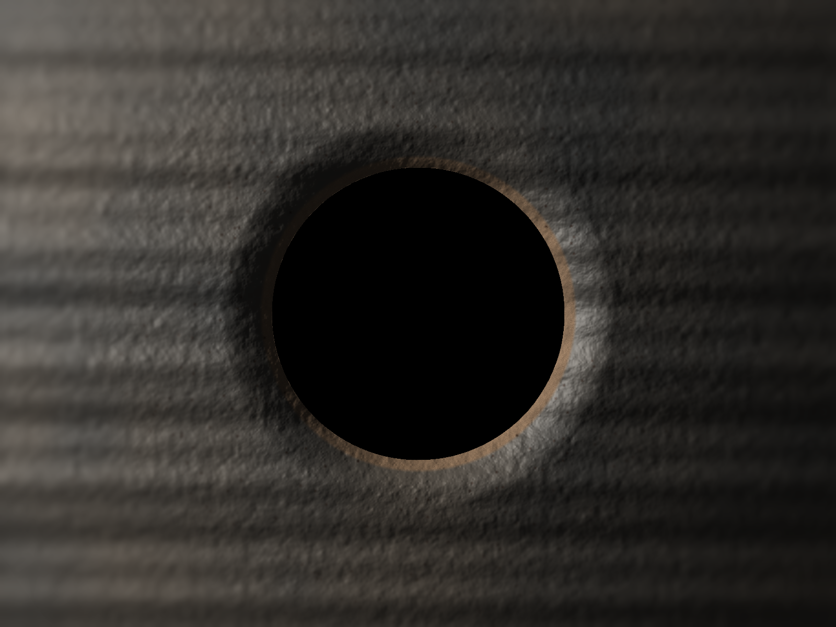
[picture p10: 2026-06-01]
images/macro/side-hole-port.png

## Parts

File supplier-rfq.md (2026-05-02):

# Supplier RFQ — Slip-Cast Ceramic Udu Drum Family (UDU-001 family)

> Use this as a template for outreach to ceramic-supply, plaster, mold-making, and finishing suppliers. Customize the Subject and address fields per recipient.

**Subject:** RFQ — slip-cast ceramic udu drum prototype materials and consumables

Hello,

I'm a mechanical R&D engineer prototyping a small family of slip-cast ceramic udu drums (Igbo-rooted clay vessel drum, S/M/L/XL sizes, ~8-14 in body diameter, ~0.30 in / 7.6 mm wall) and need quotes for the following. The first build is a Medium standard udu (10 in dia × 12 in tall, target mouth tone B3 ≈ 247 Hz, side-hole tone G3 ≈ 196 Hz) based on the parametric dual-Helmholtz design table at [tonykoop/udu](https://github.com/tonykoop/udu).

## Items

| # | Item | Required spec | Approx. qty (per prototype run) |
|---|---|---|---|
| 1 | Cone 6 stoneware casting slip | Mature Cone 6 stoneware slip with **published shrinkage** (X/Y/Z), **water absorption %**, and **firing schedule**. Larger pour volumes than typical small-vessel work — slip needs to flow predictably into a 12+ in master cavity without cracking on drain. | 5 gal (Medium) — 15 gal (S/M/L/XL set) |
| 2 | #1 pottery plaster (large mold scale) | USG #1 Pottery Plaster (or equivalent) suitable for a 16 × 14 × 4 in two-piece pour. Need **water:plaster ratio**, **set time**, and **dimensional stability** (creep) over months of use. | 50 lb (single Medium mold) — 200 lb (full S/M/L/XL set) |
| 3 | Mold release / mold soap | Plaster-compatible parting agent. Larger surface area than small vessels — needs to release cleanly off a 12+ in body without locking. | 2 bottles / 32 oz |
| 4 | Cone 6 exterior glaze | Satin or matte glaze. **Color: TBD** — earth tones / iron oxide / rust red are visually closer to traditional fired Igbo-clay ware. Glaze must NOT bridge mouth or side-hole edges (acoustic-critical). | 1-2 pints per body |
| 5 | Brushable wax resist | Standard ceramic wax resist for masking mouth rim, side-hole rim, and chamber interior pre-glaze. | 1 jar / 16 oz |
| 6 | Hole cutter set | Round cutters, **1.5 in to 3 in diameter**, for greenware side-hole cutting. Brass tube cutters or commercial hole-cutter discs both acceptable. | 1 set |
| 7 | Diamond needle file / burr set (post-bisque tuning) | Assorted profiles, **3-10 mm**; resin-bonded acceptable. Used to enlarge ports for pitch correction. | 1 set |
| 8 | Bisque + glaze firing service (if local) | Cone 06 bisque + Cone 6 glaze fire; medium-large kiln (10 ft³+) can fit XL family. | 2 fires per body |
| 9 | (Optional) Master printing / outsource | Large-format PLA or resin print, up to **~14 in master width** with **0.010 in dimensional accuracy**. We currently print in-house but want a backup option. | 1-4 master pairs (S/M/L/XL) |
| 10 | (Optional) Rubber feet — low-profile | Self-adhesive low-profile rubber feet, ~0.5 in dia, for floor stability. Test-fit only — feet damp shell tap tone, so this is an acoustic trade-off. | 3 per body |
| 11 | (Optional) Piezo / contact pickup | Contact pickup that can survive being epoxied to interior wall OR magnetically/clip-mounted externally. | 1 per electric variant |

## What we need in your quote

- **Unit price** and any volume breaks
- **Minimum order quantity**
- **Current stock status** and **lead time**
- **Shipping estimate** to 94566 (Pleasanton, CA) — or local pickup option
- **Material safety data sheet (MSDS)** and **technical data sheet** for items 1, 2, 4, 5
- **Recommended substitutions** if anything goes out of stock
- For item 1: most recent **shrinkage test data** for your batch (we re-measure on our side, but a baseline matters)
- For item 9: **photos of similar-sized prints** showing layer-line consistency and dimensional check process

## Acceptance criteria

The prototypes are measured for X/Y/Z shrinkage, fired chamber volume (water-fill), wall-thickness consistency at rim/shoulder/belly/foot, and acoustic tuning at TWO conditions: mouth-tone (mouth open, side covered) and side-hole tone (side open, mouth covered or hand-muted). Target tuning tolerance: **±50 cents post-bisque** on both modes for the Medium body. Slip with unknown or wildly variable shrinkage invalidates the master scale factor (currently `1/(1-0.12) = 1.136`), so reproducibility data matters more than headline price.

The repo is a private R&D portfolio repo; we do not need any IP-restricted documents. Public-domain MSDS and supplier spec sheets are sufficient.

## Cultural note for sales / marketing teams

The udu has Igbo (Nigerian) roots and is not a generic ceramic bass pot. We're not asking for marketing positioning — we're asking for materials. But please don't include "decorative African pot" or similar reductive copy in any spec sheet response. Lineage attribution belongs to the player and the documentation, not the supplier.

Thank you,

Tony Koop
Mechanical R&D Engineer
tonykoop@gmail.com
github.com/tonykoop/udu (private; access on request)

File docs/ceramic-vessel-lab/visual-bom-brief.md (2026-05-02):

# Udu Visual BOM Brief

## Goal

Create a one-page visual BOM for the slip-cast udu family that shows the body, mold, ports, finishing choices, and optional electric/water variants.

## Layout

- Header: "Slip-Cast Ceramic Udu Drum Family".
- Hero image: medium udu render or finished prototype.
- Family strip: small, medium, large, XL silhouettes with target pitch ranges.
- Exploded/process view: 3D printed master halves, plaster mold halves, cast body, side-hole cut, fired body.
- BOM table: item number, material/tool, quantity, spec, cost estimate, make/buy, image.
- Physics inset: top-port and side-port Helmholtz formulas.
- Measurement inset: body volume, mouth tone, side tone, wall thickness, mass.

## Image Requirements

Use real photos as soon as available:

- Printed master.
- Plaster mold halves.
- Leather-hard cast before side-hole cutting.
- Side-hole close-up.
- Fired body with hand scale.
- Optional pickup or rubber-foot detail.

Generated or CAD images should be marked as placeholders until replaced by shop photos.

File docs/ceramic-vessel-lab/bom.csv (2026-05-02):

item_id | category | item | qty | spec | make_buy | estimated_cost | source_note | drawing_ref | notes
UDU-BOM-001 | Clay | Cone 6 casting slip | 5 gal | Commercial premixed stoneware casting slip | Buy | $35-50 | Workbook estimate not date-checked | UDU-DRW-003 | Enough for roughly 8-12 medium udus per workbook note.
UDU-BOM-002 | Mold | #1 pottery plaster | 50 lb | Pottery plaster for 2-piece mold | Buy | $25-35 | Workbook estimate not date-checked | UDU-DRW-002 | Record plaster ratio and mold dry weight.
UDU-BOM-003 | Master | 3D printed master | 2 halves | PLA master scaled for shrinkage | Make | $5-15 | Workbook estimate not date-checked | UDU-DRW-001 | Sand and seal before mold making.
UDU-BOM-004 | Mold | Mold soap/release | 1 bottle | Plaster-compatible release | Buy | $8-12 | Workbook estimate not date-checked | UDU-DRW-002 | Use on sealed master and plaster parting faces.
UDU-BOM-005 | Cutting | Hole cutter set | 1 set | 1.5 in to 3 in round cutters | Buy | $10-20 | Workbook estimate not date-checked | UDU-DRW-004 | Cut side hole at leather-hard stage.
UDU-BOM-006 | Firing | Bisque and glaze firing | 2 fires | Cone 06 bisque and Cone 6 glaze | Buy | $20-50/fire | Workbook estimate not date-checked | UDU-VAL-002 | Record schedule and kiln.
UDU-BOM-007 | Finish | Exterior glaze | 1 pint | Cone 6 matte or satin glaze | Buy | $10-20 | Workbook estimate not date-checked | UDU-DRW-005 | Leave interior unglazed.
UDU-BOM-008 | Hardware | Rubber feet | 1 set | Three low-profile feet | Buy | $3-5 | Workbook estimate not date-checked | UDU-DRW-006 | Optional; test effect on shell resonance.
UDU-BOM-009 | Electronics | Contact pickup | 1 | Piezo disc/contact mic | Buy | $15-30 | Workbook estimate not date-checked | UDU-DRW-007 | Optional electric variant.
UDU-BOM-010 | Measurement | Water-fill and frequency measurement kit | 1 | Graduated vessel plus tuner/mic | Buy | TBD | Add supplier/date before purchase | UDU-VAL-003 | Required for empirical correction loop.

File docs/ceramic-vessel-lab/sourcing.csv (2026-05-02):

item_id | item | required_spec | search_terms | supplier_candidates | date_checked | unit_price | lead_time | substitution_rule | risk_note
UDU-SRC-001 | Cone 6 casting slip | Stoneware casting slip with known shrinkage and mature Cone 6 schedule | cone 6 stoneware casting slip 5 gallon shrinkage | TBD |  |  |  | Substitute only with shrinkage test bars | Unknown shrinkage changes volume and pitch.
UDU-SRC-002 | #1 pottery plaster | Absorbent pottery mold plaster in 50 lb quantity | USG #1 pottery plaster 50 lb | TBD |  |  |  | Equivalent pottery plaster acceptable if absorption is proven | Weak plaster shortens mold life.
UDU-SRC-003 | PLA filament | Stable print material for large master halves | PLA filament large format mold master | TBD |  |  |  | Resin or outsourced print acceptable if sealed | Print warping changes mold volume.
UDU-SRC-004 | Mold release | Plaster-compatible parting/release compound | pottery mold soap plaster release | TBD |  |  |  | Use known ceramic mold release | Release failure can destroy the master.
UDU-SRC-005 | Hole cutters | Clean round cutters from 1.5 in to 3 in | ceramic hole cutter round clay 2 inch 3 inch | TBD |  |  |  | Custom brass tube cutters acceptable | Ragged side hole edge hurts playability.
UDU-SRC-006 | Rubber feet | Low profile feet with adhesive or mechanical mount | rubber feet ceramic instrument low profile | TBD |  |  |  | Use removable feet during acoustic tests | Feet can damp shell tap tone.
UDU-SRC-007 | Piezo pickup | Contact pickup that can survive installation method | piezo disc contact pickup drum ceramic | TBD |  |  |  | External contact mic acceptable for prototype | Internal epoxy is hard to reverse.

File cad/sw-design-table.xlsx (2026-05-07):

Design Table for: UDU-001_BodyMaster
 | $DESCRIPTION | $COLOR | $VALUE@target_hz_mouth@Equations | $VALUE@target_hz_side@Equations | $VALUE@body_diam_in@Equations | $VALUE@body_height_in@Equations | $VALUE@wall_thk_in@Equations | $VALUE@mouth_diam_in@Equations | $VALUE@side_diam_in@Equations | $VALUE@shape_factor@Equations | $VALUE@chamber_volume_cuin@Equations | $VALUE@predicted_hz_mouth@Equations | $VALUE@predicted_hz_side@Equations | $VALUE@cents_error_mouth@Equations | $VALUE@cents_error_side@Equations | $VALUE@master_scale_factor@Equations
UDU-S | Small/tabletop. Predictions sharp of targets — mouth dia likely needs to drop ~2.5 in OR shape factor increased to reduce predicted Hz; flag for empirical UDU-P1 measurement. | 15000804
UDU-M | Medium/standard. Workbook prototype-1 target. Predictions within ±50¢ of targets — hits the v4 design-table band. | 15000804
UDU-L | Large/deep bass. Mouth prediction flat of target — port may need to enlarge slightly OR shape factor reduced; flag for empirical UDU-L measurement. | 15000804
UDU-XL | Concert bass. Predictions flat across both ports — XL may need port scaling (mouth 3.5+ in) to recover pitch; needs stand. Flag as design risk — see risks.md. | 15000804

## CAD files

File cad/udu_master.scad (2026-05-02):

// =============================================================
// Slip-Cast Ceramic Udu Drum Family — OpenSCAD Master-Shape Starter
// =============================================================
// Generated 2026-05-02 from the UDU-001 parametric design table.
// Units: inches.  Outputs the FIRED body envelope; multiply by
// master_scale_factor to get the printed master geometry.
//
// This is a master-shape STARTER — captures body volume, mouth
// port, and side port. NOT final production CAD: rim radii,
// foot/stand-pad geometry, and surface texture must be refined
// in detailed CAD before mold-making.
//
// Family: S / M / L / XL — each row in `family[]` triggers a
// different fired body envelope from the design table.
// =============================================================

$fn = 96;

// --------- INPUT PARAMETERS (from design table) ---------------

// Speed of sound in air (inches/sec at ~68 F):
c_in_per_sec = 13510;

// Shrinkage (replace with MEASURED value per slip batch):
shrinkage = 0.12;
master_scale_factor = 1 / (1 - shrinkage);   // ~1.136 at 12% shrinkage

// Wall thickness (fired):
wall_in = 0.30;

// Shape factor (1.0 = ellipsoid, <1.0 = pinched, >1.0 = bulged):
shape_factor = 0.7;

// Family block: [name, body_dia_in, body_height_in, mouth_dia_in, side_dia_in]
family = [
    [ "UDU-S",   8.0, 10.0, 3.0, 2.0 ],   // Small  — D#4 mouth / A3 side
    [ "UDU-M",  10.0, 12.0, 3.0, 2.0 ],   // Medium — B3 mouth / G3 side  (PROTOTYPE 1)
    [ "UDU-L",  12.0, 14.0, 3.0, 2.0 ],   // Large  — G#3 mouth / D3 side
    [ "UDU-XL", 14.0, 16.0, 3.0, 2.0 ]    // XL     — F3 mouth / C3 side
];

// Which family member to render full-detail (-1 = all, 0..3 = single):
preview_index = 1;   // Medium by default

// ---------------------- FUNCTIONS ------------------------------

// Volume of an ovoid body (matches workbook formula):
function volume_ovoid(d, h, sf) = (PI/6) * d*d * h * sf;

// Helmholtz frequency (in/in/sec system):
function helmholtz_hz(area, vol, neck) = (c_in_per_sec / (2*PI)) * sqrt( area / (vol * neck) );

// End correction:
function L_eff(wall, area) = wall + 0.6 * sqrt(area / PI);

// Circle area:
function area_circle(d) = PI * (d/2) * (d/2);

// ---------------------- GEOMETRY -------------------------------

module udu_outer(diam, height, sf) {
    // Egg/pot profile — pinched at top, broad at bottom.
    hull() {
        translate([0, 0, height * 0.30])
            scale([diam/2 * 0.95, diam/2 * 0.95, height * 0.45 * sf])
                sphere(r=1);
        translate([0, 0, height * 0.85])
            scale([diam/2 * 0.55, diam/2 * 0.55, height * 0.18])
                sphere(r=1);
        // Floor — slightly flattened.
        translate([0, 0, 0])
            scale([diam/2 * 0.85, diam/2 * 0.85, height * 0.04])
                sphere(r=1);
    }
}

module udu_inner(diam, height, sf) {
    // Inner cavity (offset by wall thickness):
    hull() {
        translate([0, 0, height * 0.30])
            scale([diam/2 * 0.95 - wall_in, diam/2 * 0.95 - wall_in, height * 0.45 * sf - wall_in])
                sphere(r=1);
        translate([0, 0, height * 0.85])
            scale([diam/2 * 0.55 - wall_in, diam/2 * 0.55 - wall_in, height * 0.18 - wall_in])
                sphere(r=1);
        translate([0, 0, 0])
            scale([diam/2 * 0.85 - wall_in, diam/2 * 0.85 - wall_in, height * 0.04 - wall_in])
                sphere(r=1);
    }
}

module udu_body(diam, height, sf, mouth_dia, side_dia) {
    difference() {
        udu_outer(diam, height, sf);
        udu_inner(diam, height, sf);
        // Mouth port (top):
        translate([0, 0, height * 0.95])
            cylinder(h = wall_in * 4, d = mouth_dia, center = true);
        // Side port (left side, comfortable hand height):
        translate([-diam/2, 0, height * 0.55])
            rotate([0, 90, 0])
                cylinder(h = wall_in * 4, d = side_dia, center = true);
    }
}

module udu_master(diam, height, sf, mouth_dia, side_dia) {
    // Master = solid scaled up by shrinkage factor.
    scale([master_scale_factor, master_scale_factor, master_scale_factor])
        udu_outer(diam, height, sf);
}

// --------------------- DEFAULT PREVIEW -------------------------

if (preview_index >= 0) {
    f = family[preview_index];
    udu_body(f[1], f[2], shape_factor, f[3], f[4]);
    // Echo physics:
    V = volume_ovoid(f[1], f[2], shape_factor);
    A_top = area_circle(f[3]);
    A_side = area_circle(f[4]);
    L_top = L_eff(wall_in, A_top);
    L_side = L_eff(wall_in, A_side);
    f_top = helmholtz_hz(A_top, V, L_top);
    f_side = helmholtz_hz(A_side, V, L_side);
    echo(str(f[0], "  V=", V, " in^3  f_top=", f_top, " Hz  f_side=", f_side, " Hz"));
} else {
    // Render whole family side by side:
    for (i = [0 : len(family) - 1]) {
        f = family[i];
        translate([i * 18, 0, 0])
            udu_body(f[1], f[2], shape_factor, f[3], f[4]);
    }
}

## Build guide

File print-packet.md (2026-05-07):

# Slip-Cast Ceramic Udu Drum Family — v4.1 Capstone Print Packet

Generated: 2026-05-07
Packet folder: `/sessions/friendly-stoic-shannon/mnt/GitHub/udu`

## File Map

| File | Purpose |
| --- | --- |
| `design.md` | Project intent, catalog metadata, assumptions, and validation plan. |
| `bom.csv` | Starter bill of materials with part categories, quantities, drawing refs, and notes. |
| `sourcing.csv` | Supplier/search tracker with specs, price/date fields, lead time, substitutes, and risks. |
| `cut-list.csv` | Rough/final stock sizes, material, grain/orientation, operations, yield, and offcuts. |
| `drawing-brief.md` | Manufacturing drawing and technical product sketch brief. |
| `assembly-manual.md` | Shop-facing sequence, tools, fixtures, safety, tuning, finishing, and maintenance notes. |
| `validation.csv` | Target/measured values, tolerance, environment, result, and tuning/build action log. |
| `supplier-rfq.md` | Supplier email/request-for-quote starter. |
| `visual-bom-brief.md` | Art direction for an image-forward visual BOM. |
| `wolfram-starter.wl` | Wolfram starter for physics, optimization, visualization, and validation. |
| `README.md` | Project artifact. |
| `family-spec.csv` | Project artifact. |
| `risks.md` | Project artifact. |

## design.md

Project intent, catalog metadata, assumptions, and validation plan.

# Slip-Cast Ceramic Udu Drum Family

## Source

- Design table: `udu-design-table.xlsx` (Master_Inputs + Design_Table sheets)
- Family spec: `family-spec.csv` (S/M/L/XL members)
- SW reference: `sw-reference/` (MasterLayout convention, equation list, design-table import procedure)
- Workbook lineage: `docs/Udu.xlsx`, sheet `Udu Drum Family`, inspected range `A1:H146`
- Workbook content observed: design inputs, dual-Helmholtz calculator, four-size family, variants, playing techniques, ceramic production workflow, BOM, design notes, Wolfram notebook notes.

## Project Intent

Build a slip-cast ceramic udu family — Small / Medium / Large / XL — with
repeatable chamber volumes and two playable Helmholtz tones: the main mouth
tone and the side-hole slap tone. The first production target is the
**Medium** standard udu (UDU-P2: 10 in × 12 in body, B3 mouth / G3 side),
followed by a scaled family. The udu (Igbo: *ụdụ*, "vessel") is a Nigerian
clay-vessel drum and the documentation here treats that lineage as fact, not
marketing.

The repository is the engineering artifact for the dual-Helmholtz coupled-
resonator model: parametric design table → 3D-printed master halves →
two-piece plaster mold → Cone-6 stoneware slip-cast → bisque + tune + glaze.
The same pipeline serves `ocarina/`, `gemshorn/`, and `transverse-flute/`.

## Governing Model

The udu uses a shared chamber with two coupled Helmholtz resonators:

```text
f_top  = c/(2*pi) * sqrt( A_top  / (V * L_top)  )
f_side = c/(2*pi) * sqrt( A_side / (V * L_side) )
L      = wall_thickness + 0.6 * sqrt(A/pi)
V      = (pi/6) * body_diam^2 * body_height * shape_factor
```

When both ports are open and the player's hands move, the modes couple — the
single-port formulas are useful first-order targets, and the placeholder
coupled-mode eigenvalue model lives in `wolfram-starter.wl`. Measured
prototypes define the final tuning corrections; per-family corrections feed
back through `scripts/record_measurement.py` (see
`references/empirical-learning-loop.md`).

## Hardware Alignment

This repo is one of the slip-cast targets for the in-flight Bambu printer +
ceramic kiln pipeline shared with `ocarina/`, `gemshorn/`, and
`transverse-flute/`. The build chain:

| Stage | Tool / pipeline | Notes |
| --- | --- | --- |
| Design table | `udu-design-table.xlsx` Master_Inputs | Blue cells = inputs; volume formula derived |
| Master scaling | `master_scale_factor = 1/(1 - measured_shrinkage)` | Re-derive per slip batch — see risks.md SUP-01 |
| Master print | Bambu X1C (UDU-S, UDU-M) or outsourced print (UDU-L, UDU-XL) | X1C envelope ≈ 256 mm; L/XL exceed it — see risks.md SUP-02 |
| Mold | Two-piece plaster mother mold, USG #1 pottery plaster | Split line off the hand-contact equator |
| Cast | Cone 6 stoneware casting slip | Shrinkage coupon required per batch |
| Trim | Side hole cut at leather-hard, undersized | Final tune at bisque |
| Fire | Cone 06 bisque → Cone 6 glaze | Glaze exterior only |
| Validate | `validation.csv` mouth/side/coupled measurements | `record_measurement.py` updates per-family corrections |
| CAD round-trip | `UDU-000_MasterLayout.SLDPRT` ↔ `cad/sw-design-table.xlsx` | See `sw-reference/` for the SW workflow |

## Current Workbook Inputs

| Field | Current value |
| --- | --- |
| Body diameter | 10 in |
| Body height | 12 in |
| Wall thickness | 0.3 in |
| Mouth diameter | 3 in |
| Side hole diameter | 2 in |
| Shape factor | 0.7 |
| Clay body | Cone 6 stoneware |
| Shrinkage | 0.12 |
| Speed of sound | 13510 in/s |

## Current Family Targets

| Model | Diameter | Height | Volume | Mouth tone | Side tone | Use |
| --- | ---: | ---: | ---: | --- | --- | --- |
| Small | 8 in | 10 in | 235 in3 | D#4 | A3 | Tabletop and high tones |
| Medium | 10 in | 12 in | 440 in3 | B3 | G3 | Most versatile standard size |
| Large | 12 in | 14 in | 739 in3 | G#3 | D3 | Deep bass and traditional feel |
| XL | 14 in | 16 in | 1149 in3 | F3 | C3 | Concert bass, likely needs stand |

## Critical Design Features

- Body volume controls both main tones; slip casting is valuable because it makes volume repeatable.
- Port diameters and effective neck lengths are the main pitch controls.
- Wall thickness controls shell tap tone, durability, drying risk, and weight more than Helmholtz pitch.
- The side hole edge must be comfortable for repeated hand slaps.
- The mouth rim should be rounded enough for comfort but consistent enough for repeatable hand sealing.
- Feet, stand interface, or flat area should be designed before the mold if the instrument needs stability.

## Cultural And Product Note

The udu ha

## bom.csv

Starter bill of materials with part categories, quantities, drawing refs, and notes.

| item_id | category | item | qty | spec | make_buy | estimated_cost | source_note | drawing_ref | notes |
| --- | --- | --- | --- | --- | --- | --- | --- | --- | --- |
| UDU-BOM-001 | Clay | Cone 6 casting slip | 5 gal | Commercial premixed stoneware casting slip | Buy | $35-50 | Workbook estimate not date-checked | UDU-DRW-003 | Enough for roughly 8-12 medium udus per workbook note. |
| UDU-BOM-002 | Mold | #1 pottery plaster | 50 lb | Pottery plaster for 2-piece mold | Buy | $25-35 | Workbook estimate not date-checked | UDU-DRW-002 | Record plaster ratio and mold dry weight. |
| UDU-BOM-003 | Master | 3D printed master | 2 halves | PLA master scaled for shrinkage | Make | $5-15 | Workbook estimate not date-checked | UDU-DRW-001 | Sand and seal before mold making. |
| UDU-BOM-004 | Mold | Mold soap/release | 1 bottle | Plaster-compatible release | Buy | $8-12 | Workbook estimate not date-checked | UDU-DRW-002 | Use on sealed master and plaster parting faces. |
| UDU-BOM-005 | Cutting | Hole cutter set | 1 set | 1.5 in to 3 in round cutters | Buy | $10-20 | Workbook estimate not date-checked | UDU-DRW-004 | Cut side hole at leather-hard stage. |
| UDU-BOM-006 | Firing | Bisque and glaze firing | 2 fires | Cone 06 bisque and Cone 6 glaze | Buy | $20-50/fire | Workbook estimate not date-checked | UDU-VAL-002 | Record schedule and kiln. |
| UDU-BOM-007 | Finish | Exterior glaze | 1 pint | Cone 6 matte or satin glaze | Buy | $10-20 | Workbook estimate not date-checked | UDU-DRW-005 | Leave interior unglazed. |
| UDU-BOM-008 | Hardware | Rubber feet | 1 set | Three low-profile feet | Buy | $3-5 | Workbook estimate not date-checked | UDU-DRW-006 | Optional; test effect on shell resonance. |
| UDU-BOM-009 | Electronics | Contact pickup | 1 | Piezo disc/contact mic | Buy | $15-30 | Workbook estimate not date-checked | UDU-DRW-007 | Optional electric variant. |
| UDU-BOM-010 | Measurement | Water-fill and frequency measurement kit | 1 | Graduated vessel plus tuner/mic | Buy | TBD | Add supplier/date before purchase | UDU-VAL-003 | Required for empirical correction loop. |

## sourcing.csv

Supplier/search tracker with specs, price/date fields, lead time, substitutes, and risks.

| item_id | item | required_spec | search_terms | supplier_candidates | date_checked | unit_price | lead_time | substitution_rule | risk_note |
| --- | --- | --- | --- | --- | --- | --- | --- | --- | --- |
| UDU-SRC-001 | Cone 6 casting slip | Stoneware casting slip with known shrinkage and mature Cone 6 schedule | cone 6 stoneware casting slip 5 gallon shrinkage | TBD |  |  |  | Substitute only with shrinkage test bars | Unknown shrinkage changes volume and pitch. |
| UDU-SRC-002 | #1 pottery plaster | Absorbent pottery mold plaster in 50 lb quantity | USG #1 pottery plaster 50 lb | TBD |  |  |  | Equivalent pottery plaster acceptable if absorption is proven | Weak plaster shortens mold life. |
| UDU-SRC-003 | PLA filament | Stable print material for large master halves | PLA filament large format mold master | TBD |  |  |  | Resin or outsourced print acceptable if sealed | Print warping changes mold volume. |
| UDU-SRC-004 | Mold release | Plaster-compatible parting/release compound | pottery mold soap plaster release | TBD |  |  |  | Use known ceramic mold release | Release failure can destroy the master. |
| UDU-SRC-005 | Hole cutters | Clean round cutters from 1.5 in to 3 in | ceramic hole cutter round clay 2 inch 3 inch | TBD |  |  |  | Custom brass tube cutters acceptable | Ragged side hole edge hurts playability. |
| UDU-SRC-006 | Rubber feet | Low profile feet with adhesive or mechanical mount | rubber feet ceramic instrument low profile | TBD |  |  |  | Use removable feet during acoustic tests | Feet can damp shell tap tone. |
| UDU-SRC-007 | Piezo pickup | Contact pickup that can survive installation method | piezo disc contact pickup drum ceramic | TBD |  |  |  | External contact mic acceptable for prototype | Internal epoxy is hard to reverse. |

## cut-list.csv

Rough/final stock sizes, material, grain/orientation, operations, yield, and offcuts.

| cut_id | part | qty | rough_dimensions_in | final_dimensions_in | material | orientation | operation | tolerance_in | yield_or_offcut | notes |
| --- | --- | --- | --- | --- | --- | --- | --- | --- | --- | --- |
| UDU-CUT-001 | Master body upper half (3D-printed) — Medium | 1 | 12 x 12 x 7 envelope | master scaled by 1/(1-shrinkage); ~1.136x at 12% shrinkage | PLA or sealable resin | Z up; mark mouth axis + side-hole datum | Print in 2-3 sessions; sand layer lines; fill voids; seal | +/-0.020 | Reuse offcut sprues for shrinkage coupons | Master scale factor must be re-derived from MEASURED clay shrinkage before final master. |
| UDU-CUT-002 | Master body lower half (3D-printed) — Medium | 1 | 12 x 12 x 7 envelope | mirror of UDU-CUT-001 | PLA or sealable resin | Z up; mark split-line datum | Print sand fill seal | +/-0.020 | Reuse offcut sprues | Same scale factor as UDU-CUT-001. |
| UDU-CUT-003 | Wooden cottle boards (mold making) | 4 | 18 x 16 x 0.75 each | 16 x 14 x 0.75 each | Melamine-faced MDF | Smooth face inward; mark inner clamping zone | Cut edge-seal drill clamping holes | +/-0.030 | One sheet of 4ft x 8ft x 0.75 yields all 4 plus 50% of next mold set | Clean parting wax/release before each pour. |
| UDU-CUT-004 | Plaster mother mold half (poured) — Medium | 2 | 16 x 14 x 4 each | 16 x 14 x 3.5-3.75 each (around master) | USG #1 pottery plaster (or equiv.) | Pour with master keyed to first half; second half over registration | Mix to 73:100 water:plaster (by weight); 2-min slake; pour around sealed master | +/-0.10 | Trim spew/edge after demold; recover small offcuts as test slabs | Min 1.50 in plaster around master; 2.0 in preferred for medium-size pour stiffness. |
| UDU-CUT-005 | Greenware vessel (slip-cast) — Medium | 1 per pour | master cavity wet (~12 x 14 x 7 OD) | ~10.6 x 12.4 x 6.2 fired (12% shrink) | Cone 6 stoneware casting slip | Mouth axis along master split | Slip pour > drain at target wall (~0.30 in / 7.6 mm) > demold leather-hard | N/A (process-controlled) | Reuse demold trim/fettling waste as slip recycle | Wall thickness drives drying time and tap tone — measure on noncritical trim. |
| UDU-CUT-006 | Mouth opening (cast as part of master) | 1 | N/A | 3.0 in dia FIRED (=3.41 in master) | Cone 6 greenware | Top of body — central | Cast cleanly via mold shape; rim-round at leather-hard | +/-0.030 | N/A | Round rim radius for repeated hand-seal comfort. |
| UDU-CUT-007 | Side hole (leather-hard cut) | 1 per body | N/A | 2.0 in dia FIRED | Cone 6 greenware | Side of body at hand-comfort height | Brass tube cutter or hole punch at leather-hard; clean burr with damp finger | +/-0.030 (start) | N/A | Cut undersized; final tune at bisque if pitch off >50 cents. |
| UDU-CUT-008 | Foot pads (optional — cast-in or applied) | 3 per body | N/A | ~0.5 in dia x 0.10 in tall | Rubber adhesive feet OR cast-in clay foot | Tripod 120 deg around base | Apply post-glaze fire OR cast as part of master | +/-0.030 | N/A | Test with and without feet; feet damp shell tap tone (acoustic trade-off). |
| UDU-CUT-009 | Post-bisque tuning trim | as needed | N/A | Within +/-50 cents of target frequency per validation.csv | Bisqued ceramic | N/A | Diamond burr in steps; enlarge mouth or side hole to raise pitch | +/-0.020 dimensional; +/-50 cents acoustic | N/A | Document each enlarge step on validation row. Hand coupling shifts perceived pitch — measure both with and without hand seal. |
| UDU-CUT-010 | Wax resist mask (pre-glaze) | 1 application | N/A | ~0.020 in dry film over mouth rim + side hole edge + interior | Brushable wax resist | N/A | Brush-apply; dry per supplier; check all openings clear | Visual | N/A | Mask edges where hand contact happens to keep glaze surface clean. |
| UDU-CUT-011 | Glaze application (exterior only) | 1 application | N/A | ~0.010-0.020 in per coat; 1 coat exterior matte | Cone 6 satin or matte glaze | Avoid waxed regions and mouth/side-hole interiors | Dip / brush / spray exterior only | +/-0.010 (visual) | N/A | Heavy glaze damps shell tap. Keep coat thin. |
| UDU-CUT-012 | Family scaling — Small / Large / XL master variants | 1 set each | Per design table family-spec rows | Per design table fired dimensions | Same as UDU-CUT-001/002 | Per family | Print/master/mold parallel pipeline once Medium voicing is stable | +/-0.025 | Each size needs its own cottle set | Defer until UDU-P2 medium prototype validates wall thickness + mouth/side ratio. |

## drawing-brief.md

Manufacturing drawing and technical product sketch brief.

# Udu Drum Family Drawing Brief

## Required Views

- Front view with overall height, max body diameter, mouth diameter, and side-hole position.
- Side view showing body profile, wall target, side-hole axis, and foot/stand contact.
- Top view showing mouth opening, rim radius, and symmetry datums.
- Section view through mouth and side hole showing wall thickness and effective neck length.
- Mold split view with registration keys, plaster thickness, pour/drain direction, and seam-cleanup zone.
- Optional electric variant view showing piezo location, wire path, jack location, and service access.

## Critical Dimensions

| Dimension | Source | Tolerance intent |
| --- | --- | --- |
| Chamber volume | Workbook formula and water-fill measurement | Tuning critical |
| Body diameter and height | Workbook inputs | Tuning and ergonomics |
| Mouth diameter | Workbook input | Tuning and hand seal |
| Side-hole diameter | Workbook input and tuning log | Tuning and playability |
| Wall thickness | Workbook input and cast measurement | Tap tone/durability |
| Rim radii | CAD and ergonomic test | Comfort |
| Master scale factor | Measured clay shrinkage | Process critical |

## Notes For CAD

- Use a named shape factor or profile parameter so S/M/L/XL can be regenerated from the same model.
- Keep side-hole position as a parameter tied to hand comfort, not only aesthetics.
- Design any feet as optional variants so acoustic damping can be tested.
- Keep the water-udu variant separate because water fill and leak-tightness change requirements.

## assembly-manual.md

Shop-facing sequence, tools, fixtures, safety, tuning, finishing, and maintenance notes.

# Udu Drum Family Assembly Manual

## Scope

This manual covers slip-cast ceramic udu prototypes based on `docs/Udu.xlsx`, starting with the medium standard udu and expanding to a scaled family.

## Tools

- CAD package for body profile and mold split.
- Large-format 3D printer or outsourced print for master halves.
- Plaster mold-making setup: cottle boards, scale, bucket, plaster, mold soap, clamps.
- Cone 6 stoneware casting slip.
- Hole cutters, ribs, sponges, fettling knife, rasp, and small files.
- Calipers, wall-thickness gauge if available, graduated water-fill vessel, tuner/microphone.
- Kiln access, wax resist, exterior glaze.
- Optional: rubber feet, stand prototype, piezo/contact mic.

## Process

1. **Choose size**
   - Start with the medium workbook design unless testing mold workflow at smaller scale.
   - Assign build ID and expected shrinkage.

2. **CAD body and mold strategy**
   - Model the target fired body first.
   - Add shrinkage scale to produce the master body.
   - Choose a split line that releases cleanly and avoids hand-contact ridges.

3. **Print and seal master**
   - Print master halves rigid enough for plaster.
   - Sand high layer lines, fill defects, and seal.
   - Verify master diameter and height before molding.

4. **Make plaster mold**
   - Apply release.
   - Pour mold halves with registration keys.
   - Dry completely before first casting.
   - Record mold dry weight and first-use date.

5. **Slip cast**
   - Fill mold with slip.
   - Drain after target wall thickness buildup.
   - Record fill time, drain time, slip batch, room condition, and demold time.

6. **Leather-hard work**
   - Clean seam.
   - Cut side hole undersized or at first target.
   - Round mouth and side-hole edges.
   - Add foot/stand features only if they do not trap drying stress.

7. **Dry**
   - Dry under plastic for even moisture.
   - Rotate periodically if needed.
   - Inspect rim, side hole, foot, and seam.

8. **Bisque fire**
   - Fire to the clay body's bisque schedule.
   - Measure dimensions, chamber volume, mass, and pitch.

9. **Tune**
   - Tune with small changes and document each pass.
   - For simple open-port Helmholtz behavior, larger port area usually raises resonance; hand-covered playing conditions should be measured separately.
   - Do not remove more material until the measurement setup is repeatable.

10. **Glaze**
    - Glaze exterior only unless intentionally testing interior glaze damping.
    - Keep mouth and side-hole edges clean.

11. **Final validation**
    - Measure final tones, shell tap, weight, stability, and ergonomics.
    - Record whether feet or stands damp the ceramic tap tone.

## Failure Modes To Watch

- Cracks at side hole: hole cut too late, edge too sharp, or drying too fast.
- Dead bass response: chamber too small, ports poorly proportioned, walls too thick, or hand seal poor.
- Uncomfortable slap edge: rim needs larger radius or smoother fired edge.
- Warped base: unsupported drying or uneven mold thickness.
- Over-damped shell: glaze too heavy, feet too soft, or wall too thick.

## validation.csv

Target/measured values, tolerance, environment, result, and tuning/build action log.

| build_id | stage | date | model | clay_body | shrinkage_expected_pct | master_scale_factor | body_diam_in | body_height_in | wall_thickness_in | chamber_volume_in3 | mouth_diam_in | side_hole_diam_in | condition | target_note | target_freq_hz | measured_freq_hz | cents_error | action | result | notes |
| --- | --- | --- | --- | --- | --- | --- | --- | --- | --- | --- | --- | --- | --- | --- | --- | --- | --- | --- | --- | --- |
| UDU-P1 | greenware |  | Small |  |  |  | 8 | 10 | TBD | TBD | 3 | 2 | mouth_open | D#4 | 311 |  |  |  |  | First slip-cast body check. |
| UDU-P1 | bisque |  | Small |  |  |  | TBD | TBD | TBD | TBD | TBD | TBD | mouth_open | D#4 | 311 |  |  |  |  | Measure after shrinkage. |
| UDU-P1 | bisque |  | Small |  |  |  | TBD | TBD | TBD | TBD | TBD | TBD | side_open | A3 | 223 |  |  |  |  | Check hand slap response. |
| UDU-P2 | greenware |  | Medium |  |  |  | 10 | 12 | 0.3 | 440 | 3 | 2 | mouth_open | B3 | 249 |  |  |  |  | Workbook standard target. |
| UDU-P2 | bisque |  | Medium |  |  |  | TBD | TBD | TBD | TBD | TBD | TBD | mouth_open | B3 | 249 |  |  |  |  | Primary tuning checkpoint. |
| UDU-P2 | bisque |  | Medium |  |  |  | TBD | TBD | TBD | TBD | TBD | TBD | side_open | G3 | 192 |  |  |  |  | Record whether perceived pitch matches formula. |
| UDU-P2 | glaze_fire |  | Medium |  |  |  | TBD | TBD | TBD | TBD | TBD | TBD | mouth_open | B3 | 249 |  |  |  |  | Measure glaze shift. |
| UDU-P3 | bisque |  | Water udu |  |  |  | TBD | TBD | TBD | TBD | TBD | TBD | tilt_sweep | TBD | TBD |  |  |  |  | Record water amount and sweep range. |

## supplier-rfq.md

Supplier email/request-for-quote starter.

# Supplier RFQ — Slip-Cast Ceramic Udu Drum Family (UDU-001 family)

> Use this as a template for outreach to ceramic-supply, plaster, mold-making, and finishing suppliers. Customize the Subject and address fields per recipient.

**Subject:** RFQ — slip-cast ceramic udu drum prototype materials and consumables

Hello,

I'm a mechanical R&D engineer prototyping a small family of slip-cast ceramic udu drums (Igbo-rooted clay vessel drum, S/M/L/XL sizes, ~8-14 in body diameter, ~0.30 in / 7.6 mm wall) and need quotes for the following. The first build is a Medium standard udu (10 in dia × 12 in tall, target mouth tone B3 ≈ 247 Hz, side-hole tone G3 ≈ 196 Hz) based on the parametric dual-Helmholtz design table at [tonykoop/udu](https://github.com/tonykoop/udu).

## Items

| # | Item | Required spec | Approx. qty (per prototype run) |
|---|---|---|---|
| 1 | Cone 6 stoneware casting slip | Mature Cone 6 stoneware slip with **published shrinkage** (X/Y/Z), **water absorption %**, and **firing schedule**. Larger pour volumes than typical small-vessel work — slip needs to flow predictably into a 12+ in master cavity without cracking on drain. | 5 gal (Medium) — 15 gal (S/M/L/XL set) |
| 2 | #1 pottery plaster (large mold scale) | USG #1 Pottery Plaster (or equivalent) suitable for a 16 × 14 × 4 in two-piece pour. Need **water:plaster ratio**, **set time**, and **dimensional stability** (creep) over months of use. | 50 lb (single Medium mold) — 200 lb (full S/M/L/XL set) |
| 3 | Mold release / mold soap | Plaster-compatible parting agent. Larger surface area than small vessels — needs to release cleanly off a 12+ in body without locking. | 2 bottles / 32 oz |
| 4 | Cone 6 exterior glaze | Satin or matte glaze. **Color: TBD** — earth tones / iron oxide / rust red are visually closer to traditional fired Igbo-clay ware. Glaze must NOT bridge mouth or side-hole edges (acoustic-critical). | 1-2 pints per body |
| 5 | Brushable wax resist | Standard ceramic wax resist for masking mouth rim, side-hole rim, and chamber interior pre-glaze. | 1 jar / 16 oz |
| 6 | Hole cutter set | Round cutters, **1.5 in to 3 in diameter**, for greenware side-hole cutting. Brass tube cutters or commercial hole-cutter discs both acceptable. | 1 set |
| 7 | Diamond needle file / burr set (post-bisque tuning) | Assorted profiles, **3-10 mm**; resin-bonded acceptable. Used to enlarge ports for pitch correction. | 1 set |
| 8 | Bisque + glaze firing service (if local) | Cone 06 bisque + Cone 6 glaze fire; medium-large kiln (10 ft³+) can fit XL family. | 2 fires per body |
| 9 | (Optional) Master printing / outsource | Large-format PLA or resin print, up to **~14 in master width** with **0.010 in dimensional accuracy**. We currently print in-house but want a backup option. | 1-4 master pairs (S/M/L/XL) |
| 10 | (Optional) Rubber feet — low-profile | Self-adhesive low-profile rubber feet, ~0.5 in dia, for floor stability. Test-fit only — feet damp shell tap tone, so this is an acoustic trade-off. | 3 per body |
| 11 | (Optional) Piezo / contact pickup | Contact pickup that can survive being epoxied to interior wall OR magnetically/clip-mounted externally. | 1 per electric variant |

## What we need in your quote

- **Unit price** and any volume breaks
- **Minimum order quantity**
- **Current stock status** and **lead time**
- **Shipping estimate** to 94566 (Pleasanton, CA) — or local pickup option
- **Material safety data sheet (MSDS)** and **technical data sheet** for items 1, 2, 4, 5
- **Recommended substitutions** if anything goes out of stock
- For item 1: most recent **shrinkage test data** for your batch (we re-measure on our side, but a baseline matters)
- For item 9: **photos of similar-sized prints** showing layer-line consistency and dimensional check process

## Acceptance criteria

The prototypes are measured for X/Y/Z shrinkage, fired chamber volume (water-fill), wall-thickness consistency at rim/shoulder/belly/foot, and acoustic tuning at TWO conditions: mouth-tone (mouth open, side covered) and side-hole tone (side open, mouth covered or hand-muted). Target tuning tolerance: **±50 cents post-bisque** on both modes for the Medium body. Slip with unknown or wildly variable shrinkage invalidates the master scale factor (currently `1/(1-0.12) = 1.136`), so reproducibility data matters more than headline price.

The repo is a private R&D portfolio repo; we do not need any IP-restricted documents. Public-domain MSDS and supplier spec sheets are sufficient.

## Cultural note for sales / marketing teams

The udu has Igbo (Nigerian) roots and is not a generic ceramic bass pot. We're not asking for marketing positioning — we're asking for materials. But please don't include "decorative African pot" or similar reductive copy in any spec sheet response. Lineage attribution belongs to the player and the documentation, not the supplier.

Thank you,

Tony Koop
Mechanical R&D Engineer
tonykoop@gmail.com
github.com/tonykoop/udu (private; access on request)

## visual-bom-brief.md

Art direction for an image-forward visual BOM.

# Udu Visual BOM Brief

## Goal

Create a one-page visual BOM for the slip-cast udu family that shows the body, mold, ports, finishing choices, and optional electric/water variants.

## Layout

- Header: "Slip-Cast Ceramic Udu Drum Family".
- Hero image: medium udu render or finished prototype.
- Family strip: small, medium, large, XL silhouettes with target pitch ranges.
- Exploded/process view: 3D printed master halves, plaster mold halves, cast body, side-hole cut, fired body.
- BOM table: item number, material/tool, quantity, spec, cost estimate, make/buy, image.
- Physics inset: top-port and side-port Helmholtz formulas.
- Measurement inset: body volume, mouth tone, side tone, wall thickness, mass.

## Image Requirements

Use real photos as soon as available:

- Printed master.
- Plaster mold halves.
- Leather-hard cast before side-hole cutting.
- Side-hole close-up.
- Fired body with hand scale.
- Optional pickup or rubber-foot detail.

Generated or CAD images should be marked as placeholders until replaced by shop photos.

## wolfram-starter.wl

Wolfram starter for physics, optimization, visualization, and validation.

```wolfram
(* Udu drum family Helmholtz notebook starter *)

ClearAll["Global`*"];

c = 13510; (* in/s at about 68 F *)

areaCircle[d_] := Pi*(d/2)^2;
leff[wall_, area_] := wall + 0.6*Sqrt[area/Pi];
volumeOvoid[diam_, height_, shapeFactor_] := Pi/6*diam^2*height*shapeFactor;
helmholtzHz[area_, volume_, neckLength_] :=
  (c/(2*Pi))*Sqrt[area/(volume*neckLength)];
centsError[measured_, target_] := 1200*Log[2, measured/target];

uduModel[name_, diam_, height_, wall_, mouthDiam_, sideDiam_, shapeFactor_] :=
 Module[{v, aMouth, aSide, lMouth, lSide},
  v = volumeOvoid[diam, height, shapeFactor];
  aMouth = areaCircle[mouthDiam];
  aSide = areaCircle[sideDiam];
  lMouth = leff[wall, aMouth];
  lSide = leff[wall, aSide];
  <|
   "Name" -> name,
   "VolumeIn3" -> v,
   "MouthHz" -> helmholtzHz[aMouth, v, lMouth],
   "SideHz" -> helmholtzHz[aSide, v, lSide],
   "IntervalSemitones" -> 12*Log[2, helmholtzHz[aMouth, v, lMouth]/helmholtzHz[aSide, v, lSide]]
  |>
 ];

models = {
  uduModel["Small", 8, 10, 0.3, 3, 2, 0.7],
  uduModel["Medium", 10, 12, 0.3, 3, 2, 0.7],
  uduModel["Large", 12, 14, 0.3, 3, 2, 0.7],
  uduModel["XL", 14, 16, 0.3, 3, 2, 0.7]
};

Dataset[models]

(* First coupled-mode placeholder: replace kCouple with measured fit. *)
coupledFrequencies[f1_, f2_, kCouple_] :=
 Sqrt[Eigenvalues[{{f1^2, kCouple}, {kCouple, f2^2}}]];
```

## README.md

Project artifact.

# Udu — Slip-Cast Ceramic Vessel Drum Family

> *Engineering documentation for a 3D-printed-master, plaster-mold, cone-6-stoneware slip-cast udu drum family — from dual-Helmholtz physics through the parametric design table to a manufacturable build packet.*

Hero — AI-generated concept render of a Medium slip-cast udu (placeholder until first prototype is photographed)
*AI-generated concept render — replace with photo of first UDU-P2 (Medium) prototype after firing. Manufacturing dimensions come from the parametric design table, not from this image.*

## What this is

Engineering documentation for a four-size family (Small / Medium / Large / XL) of slip-cast ceramic udu drums, built around the **dual-Helmholtz coupled-resonator** model and a 3D-printed-master / plaster-mold / Cone-6-stoneware production pipeline. The repository combines:

1. **A parametric design table** ([`udu-design-table.xlsx`](udu-design-table.xlsx)) — body diameter, body height, wall thickness, mouth diameter, side-hole diameter, shape factor, shrinkage, and a four-size family-spec block with target mouth-tone and side-tone frequencies. Master scale factor `1/(1 - measured_shrinkage)` is parameterized; for a 12% shrinkage assumption, the master scales at ~1.136×.
2. **A full build packet** ([`design.md`](design.md), [`bom.csv`](bom.csv), [`sourcing.csv`](sourcing.csv), [`cut-list.csv`](cut-list.csv), [`validation.csv`](validation.csv), [`assembly-manual.md`](assembly-manual.md), [`supplier-rfq.md`](supplier-rfq.md), [`drawing-brief.md`](drawing-brief.md), [`visual-bom-brief.md`](visual-bom-brief.md), [`wolfram-starter.wl`](wolfram-starter.wl)) — the same scaffold used across the [`tonykoop`](https://github.com/tonykoop) musical-instrument catalogue.
3. **A capstone slide deck and printable shop packet** ([`capstone-deck.pptx`](capstone-deck.pptx), [`print-packet.pdf`](print-packet.pdf)) — recruiter-facing artifacts that show the design is documented well enough that someone else could build it.

Sister repos: [`gemshorn`](https://github.com/tonykoop/gemshorn) (slip-cast horn-flute mold workflow), [`ocarina`](https://github.com/tonykoop/ocarina) (single-Helmholtz vessel-flute, sister slip-cast target), [`transverse-flute`](https://github.com/tonykoop/transverse-flute) (slip-cast workflow at larger scale), [`djembe`](https://github.com/tonykoop/djembe) (where Helmholtz-cavity-resonator analysis was originally derived for the bass tone), and [`instrument-maker`](https://github.com/tonykoop/instrument-maker) (the agent skill that generated this packet).

## Background — what makes the udu different

The udu (Igbo: *ụdụ*, "vessel") is a Nigerian clay-vessel drum: a closed ceramic body with a mouth at the top and a single side hole. Striking the mouth with a flat hand produces one resonant tone; striking the side hole produces another; opening, closing, and partly hand-covering each port lets the player slide and sweep between the two pitches. **It is not a generic ceramic bass pot.** Its lineage is specific and the documentation here treats that lineage as fact, not as marketing copy.

The governing model is **two coupled Helmholtz resonators sharing a chamber volume**:

```
f_top  = c/(2π) · √( A_top  / (V · L_top)  )
f_side = c/(2π) · √( A_side / (V · L_side) )
```

with `L = wall_thickness + 0.6·√(A/π)` (flanged-port end correction) and a coupling term that becomes important when both ports are partly open. Single-port formulas are useful **first-order** targets; the coupled-mode behavior — and especially the perceived pitch when a player's hand partly covers either port — has to be measured empirically. See [`design.md`](design.md) and [`wolfram-starter.wl`](wolfram-starter.wl) for the full treatment, including a placeholder eigenvalue model for coupled frequencies.

The practical consequence is that udu tuning is **two parametric pitches plus a player-coupled middle range**. Body volume sets the bass-end ceiling; port diameters set the upper bound; wall thickness and shape factor are secondary. Hand coupling is a sweep, not a discrete control — which is why the design table targets fall within ±50 ¢ rather than the ±25 ¢ used for fixed-pitch instruments like the ocarina.

## Family targets

The first prototype is the **Medium** body (10 in dia × 12 in tall, target mouth tone B3 ≈ 247 Hz, side tone G3 ≈ 196 Hz, chamber volume ≈ 440 in³). Once Medium voicing is stable, the same parametric model drives Small / Large / XL — see [`design.md`](design.md) and the family-spec block of [`udu-design-table.xlsx`](udu-design-table.xlsx).

| Model | Body diameter | Body height | Volume | Mouth tone | Side tone | Use |
|---|---:|---:|---:|---|---|---|
| **Small** | 8 in | 10 in | ~235 in³ | D♯4 | A3 | Tabletop, high tones |
| **Medium** *(prototype 1)* | 10 in | 12 in | ~440 in³ | B3 | G3 | Most versatile standard size |
| **Large** | 12 in | 14 in | ~739 in³ | G♯3 | D3 | Deep bass, traditional feel |
| **XL** | 14 in | 16 in | ~1149 in³ | F3 | C3 | Concert bass; needs stand |

Prototype ladder:

| Prototype | Goal | Success criteria |
|---|---|---|
| **UDU-P0** cup/port tile | Validate clay wall + tap behavior | No cracks; clear ceramic tap; clean port edge |
| **UDU-P1** Small body | Validate slip casting + side-hole slap | Measurable Helmholtz tones, comfortable slap edge |
| **UDU-P2** Medium body | Hit workbook Medium target | Mouth and side tones within ±50 ¢ post-bisque |
| **UDU-P3** Water udu | Pitch-bending volume variant | Smooth tilt-bend without leaking |
| **UDU-P4** Family molds | Scale S/M/L/XL | Predictable pitch trend across sizes |

## Hardware alignment — Bambu printer + ceramic kiln

This repo is one of the **slip-casting targets** for the in-flight Bambu printer + kiln pipeline. The build chain is:

1. Parametric design table sets fired-body dimensions.
2. Master scale factor `1/(1 - measured_shrinkage)` scales the master STL.
3. Bambu print master halves in PLA (or sealable resin); sand layer lines and seal. *Note: the Medium body is right at the edge of the Bambu X1C build envelope; XL will need a print farm split or outsourced master.*
4. Two-piece plaster mother mold around the sealed master.
5. Slip-cast Cone 6 stoneware → demold leather-hard → cut side hole undersized → bisque → tune → glaze (exterior only) → final fire.
6. Validate against [`validation.csv`](validation.csv); fold corrections back into the design table.

The same pipeline serves the [`ocarina`](https://github.com/tonykoop/ocarina), [`gemshorn`](https://github.com/tonykoop/gemshorn), and [`transverse-flute`](https://github.com/tonykoop/transverse-flute) repos.

## Repository structure

```
udu/
├── README.md                       ← you are here
├── LICENSE                         ← CC-BY 4.0
│
├── design.md                       ← dual-Helmholtz model, design intent, prototype ladder
├── udu-design-table.xlsx           ← parametric spreadsheet (formulas, blue inputs, family block)
│
├── bom.csv                         ← bill of materials
├── sourcing.csv                    ← supplier/search tracker
├── cut-list.csv                    ← rough/finished dimensions, tolerances, family scaling
├── validation.csv                  ← target/measured tuning + cents-error log
├── supplier-rfq.md                 ← RFQ template for slip / plaster / consumables
│
├── assembly-manual.md              ← shop-floor build sequence
├── drawing-brief.md                ← required views + critical dimensions for CAD
├── visual-bom-brief.md             ← visual-BOM art-direction brief
├── wolfram-starter.wl              ← dual-Helmholtz physics starter notebook
│
├── capstone-deck.{md,pptx}         ← capstone slide deck (9 slides — v1 codex skill output)
├── print-packet.{md,html,pdf}      ← combined print-ready shop packet
├── capstone-manifest.json          ← orientation manifest
│
├── cad/                            ← parametric body OpenSCAD starter (family-aware)
├── cnc/                            ← (deferred — slip-cast does not need CNC unless turning a wooden master)
├── drawings/                       ← SVG drawings: section, mold split, family scale
└── images/                         ← AI-generated concept renders (placeholders)
```

## Status

| Section | Status |
|---|---|
| Parametric design table + dual-Helmholtz model | ✓ done |
| Build packet (BOM / sourcing / cut-list / validation / RFQ) | ✓ done |
| Assembly manual + drawing brief | ✓ done |
| Wolfram physics starter (with coupled-mode placeholder) | ✓ done |
| Capstone deck + print packet | ✓ done (auto-generated, recruiter-facing) |
| Concept renders (AI-generated, captioned) | ✓ done (placeholders) |
| Parametric CAD (OpenSCAD starter, family-aware) | ✓ done (master-shape only) |
| Dimensioned drawings (SVG) | ✓ done (section + mold split + family scale) |
| Production-ready CAD (.step / .stl) | **deferred** — generated after empirical Medium-body validation |
| Coupled-mode tuning model (eigenvalue fit) | **deferred** — needs Phase-1 measured data |
| First UDU-P1 (Small) prototype build | forthcoming (Bambu + kiln pipeline) |

Tier 3 production files (.step, validated .stl, .dxf, .gcode) are **out of scope until UDU-P2 (Medium) validates wall thickness and port-pitch behavior**. See [`design.md`](design.md) "Open Assumptions" for the deferral reasoning.

## License

Released under [CC-BY 4.0](LICENSE) — original written content, design files, photographs, and physics work in this repository are mine, free to reuse and adapt with credit.

The **udu** as an instrument concept and name belongs to the Igbo people of Nigeria; the lineage attribution in [`design.md`](design.md) is part of the documentation, not a license claim.

## family-spec.csv

Project artifact.

| member_id | target_note_mouth | target_hz_mouth | target_note_side | target_hz_side | body_diam_in | body_height_in | wall_thk_in | mouth_diam_in | side_diam_in | shape_factor | chamber_volume_cuin | predicted_hz_mouth | predicted_hz_side | cents_error_mouth | cents_error_side | master_scale_factor | clay_body | shrinkage_pct | reference_repo | notes |
| --- | --- | --- | --- | --- | --- | --- | --- | --- | --- | --- | --- | --- | --- | --- | --- | --- | --- | --- | --- | --- |
| UDU-S | D#4 | 311.13 | A3 | 220.00 | 8.0 | 10.0 | 0.30 | 3.0 | 2.0 | 0.70 | 234.6 | 340.8 | 262.4 | +157 | +304 | 1.136 | Cone 6 stoneware | 12 | udu | Small/tabletop. Predictions sharp of targets — mouth dia likely needs to drop ~2.5 in OR shape factor increased to reduce predicted Hz; flag for empirical UDU-P1 measurement. |
| UDU-M | B3 | 246.94 | G3 | 196.00 | 10.0 | 12.0 | 0.30 | 3.0 | 2.0 | 0.70 | 439.8 | 248.9 | 191.6 | +14 | -39 | 1.136 | Cone 6 stoneware | 12 | udu | Medium/standard. Workbook prototype-1 target. Predictions within ±50¢ of targets — hits the v4 design-table band. |
| UDU-L | G#3 | 207.65 | D3 | 146.83 | 12.0 | 14.0 | 0.30 | 3.0 | 2.0 | 0.70 | 738.8 | 192.1 | 148.0 | -126 | +14 | 1.136 | Cone 6 stoneware | 12 | udu | Large/deep bass. Mouth prediction flat of target — port may need to enlarge slightly OR shape factor reduced; flag for empirical UDU-L measurement. |
| UDU-XL | F3 | 174.61 | C3 | 130.81 | 14.0 | 16.0 | 0.30 | 3.0 | 2.0 | 0.70 | 1148.7 | 153.9 | 118.5 | -220 | -172 | 1.136 | Cone 6 stoneware | 12 | udu | Concert bass. Predictions flat across both ports — XL may need port scaling (mouth 3.5+ in) to recover pitch; needs stand. Flag as design risk — see risks.md. |

## risks.md

Project artifact.

# Udu Drum Family — Risk Register

> Red-team pass on the slip-cast ceramic udu family (UDU-S/M/L/XL). Every risk
> below has a verifiable test attached. High-severity risks are flagged for
> Tony's decision before we commit material.

This document is the v4 obligation produced by the `red-team` specialist; the
verifier asks "is this packet internally consistent?" while red-team asks
"is this design actually safe to build?" The two are independent — a polished
self-consistent packet can still fail at the bench.

Categories enumerated below: **Acoustic**, **Structural**, **Ergonomic**,
**Supply**, **Fit/Finish**.

---

## Acoustic

### [Acoustic] Predicted frequencies diverge from workbook targets at family extremes — HIGH

**Symptom:** UDU-S mouth tone reads ~340 Hz vs D♯4 target 311 Hz (+157 ¢
sharp); UDU-XL mouth tone reads ~154 Hz vs F3 target 175 Hz (-220 ¢ flat).
Family targets at the extremes are out of reach of bisque-stage trim alone
(the trim band is roughly ±100 ¢ before the port becomes structurally
compromised or visually disproportionate).

**Mechanism:** The workbook used identical port diameters (mouth 3 in, side
2 in) and a fixed shape factor 0.70 across the family. Helmholtz frequency
scales as √(A / (V · L)), so holding A constant while V scales linearly
makes the predicted pitch scale as V^(-1/2). The targets were chosen on a
musical interval ladder (mouth tones D♯4 / B3 / G♯3 / F3 — descending major
3rd / minor 3rd / minor 3rd) but the *acoustic* scaling of the chosen
geometry doesn't match the *musical* scaling of the targets.

**Test:** Cast a one-off small body (UDU-P1) and measure the mouth tone
with a tuner before the family molds are committed. Cents error >100
on the smallest member confirms the family-level mismatch.

**Mitigation:**
- Drop the UDU-S mouth diameter to ≈2.5 in (shrinks predicted Hz back
  toward 310 Hz) and grow the UDU-XL mouth toward ≈3.5–4.0 in (grows
  predicted Hz back toward 175 Hz).
- *Or* keep ports constant and shift the family targets onto an
  acoustically-honest ladder (e.g., mouth tones at fixed volume ratios).
- Document whichever path is chosen in `family-spec.csv` and re-emit the
  per-member SVG drawings.

**Severity:** **High** — design change required, not just a manufacturing
adjustment. Escalated to Tony for decision before Tier-3 production CAD.

---

### [Acoustic] Coupled-mode pitch when both ports are partly open is not predicted — Medium

**Symptom:** A real udu's musical character is the *sweep* between the
mouth and side tones as the player covers/uncovers each port. Single-port
formulas (used in the design table and Wolfram starter) do not predict
the coupled-mode pitch or the transition curve.

**Mechanism:** Two ports sharing a chamber form a 2-DOF Helmholtz system
with eigenmodes at frequencies that are not the simple geometric mean of
the single-port frequencies. The coupling strength depends on port-area
ratio and player hand impedance.

**Test:** Build UDU-P2 (Medium), record audio at five hand conditions
(mouth fully open / 25% / 50% / 75% / fully closed against a rigid hand
seal, side hole open in each), spectrogram analysis of fundamental
frequency vs hand condition. Compare to the placeholder coupled-mode
eigenvalue model in `wolfram-starter.wl`.

**Mitigation:** Empirically calibrate the coupling term in
`wolfram-starter.wl` from the UDU-P2 measurements; record the calibrated
coupling coefficient in the per-family corrections database via
`scripts/record_measurement.py`.

**Severity:** Medium — affects predictive fidelity, not the build.
Required before declaring the physics model "validated."

---

### [Acoustic] Glaze fire shifts measured pitch — Medium

**Symptom:** A bisque-tuned udu plays sharp/flat after glaze fire. Pitch
shift typically 5–25 ¢ depending on glaze thickness and exterior coverage.

**Mechanism:** Glaze adds wall mass (lowers shell-resonance damping
slightly) and can subtly change the interior surface impedance at high
frequencies. The Helmholtz fundamental itself is dominated by chamber
volume × port area, but glaze film thickness can effectively reduce
chamber volume by 1–3% on a 1/2" wall vessel.

**Test:** Record mouth + side tones for UDU-P2 at three stages:
greenware, bisque, glaze-fire. Log all three rows in `validation.csv`
with environment (temp / RH).

**Mitigation:** Cut ports slightly under-target at leather-hard;
final-tune at bisque if needed; commit to glaze fire only when bisque
tones are within ±25 ¢ of target. Glaze interior is forbidden (already
called out in build).

**Severity:** Medium — process-controllable, not a design defect.

---

## Structural

### [Structural] Wall thickness margin at side-hole edge — Medium

**Symptom:** The side hole is cut at leather-hard and then enlarged at
bisque for tuning. Each enlargement step removes wall material around
the port. Repeated tuning cycles can leave the rim too thin (<1/8")
for hand-slap durability.

**Mechanism:** Hand slap on the port edge produces local stress
~10–20× the static body load. A 1/8" minimum wall is the rule for
Cone-6 stoneware in domestic-use vessels; below that the slap-edge
chips on first impact.

**Test:** Slap-test a UDU-P0 port-tile with measured edge thicknesses
(0.30, 0.20, 0.15, 0.10 in). Document the thickness at which the rim
chips after 100 slaps with a moderate hand.

**Mitigation:** Limit total tuning enlargement to ≤30% of original port
area. Build a tuning trim *budget* into `validation.csv`: if predicted
cents-error >100 ¢, flag the body for rebuild rather than over-trim.
Round all port edges with a damp finger / soft rib before bisque.

**Severity:** Medium — manufacturing-controllable. Becomes High on
UDU-XL where extreme cents-error correction is implied (see Acoustic
risk #1).

---

### [Structural] Greenware crack risk on long unsupported wall — Medium

**Symptom:** UDU-XL's 14" diameter × 16" tall body has a 6"+ unsupported
wall span between mouth and base after demold. Greenware shrinkage during
drying produces hoop stress; cracks initiate at the side-hole notch and
propagate vertically.

**Mechanism:** Differential drying — interior surface dries more slowly
than exterior — produces a stress gradient. Side-hole cut creates a
stress concentrator. Stoneware tensile strength at 18–22% moisture
content is ~50 PSI; predicted hoop stress at the crack location is
~30–40 PSI for the XL geometry.

**Test:** First UDU-XL casting carries a strain gauge or dot-grid on
the exterior wall; photograph at 24-hour intervals during drying;
inspect side-hole crater for crack initiation. Repeat the same protocol
on UDU-L as a sanity check.

**Mitigation:** Slow-dry under plastic sheet for 5–7 days; cut side hole
*after* initial drying, not at leather-hard. If cracks appear in the
first XL, increase wall thickness to 0.40 in for that size only and
re-emit XL drawings.

**Severity:** Medium for UDU-S/M/L (geometry is well-supported), High
for UDU-XL specifically — escalated.

---

## Ergonomic

### [Ergonomic] Side-hole height for seated player — Low

**Symptom:** Player seated on a low stool reaches across an UDU-XL
14" diameter body to slap the side hole; reach distance ~12" puts
the slap stroke off the player's natural arc.

**Mechanism:** Standing or kneeling play accommodates the larger
bodies; seated play (most common for solo recording) constrains the
side-hole height to the 9th–10th-percentile player's natural arm-arc.
For UDU-S/M the side hole at 5–6" height clears this; UDU-L/XL push
the side hole to 7–8" which is the upper edge of the comfort band.

**Test:** Mock up the UDU-XL profile in foam core; place on a 14" stand
and have three players (5th-, 50th-, 95th-percentile arm reach) play
the side hole for 60 seconds; rate comfort 1–5.

**Mitigation:** Document recommended playing position per size in
`assembly-manual.md`. UDU-XL is concert-bass with a stand; specify the
stand height so the side hole sits at the seated player's elbow.

**Severity:** Low — not a build defect; a documentation obligation.

---

### [Ergonomic] Mouth rim sharpness on hand seal — Medium

**Symptom:** Player seals the mouth with a flat hand strike. A sharp
or undercut rim cuts the palm during repeated play; even a slightly
acute angle causes redness on the heel of the palm after 10 minutes
of continuous play.

**Mechanism:** Hand seal needs full-area contact with no high points.
The fired rim profile depends on the master geometry, demold cleanup,
and any leather-hard finger-rolling. A clean radius ≥1/8" on the rim
is the comfort minimum.

**Test:** UDU-P0 cup tile carries three rim radius variants
(1/16", 1/8", 1/4"). 5-minute continuous play at each; player rates
comfort + check for skin redness.

**Mitigation:** Specify rim radius ≥1/8" in the master CAD. Roll the
rim with a damp finger / soft rib at leather-hard before bisque.
Reject any body where the rim radius reads <1/16" after demold.

**Severity:** Medium — affects long play sessions. Easy to fix at the
master geometry, hard to fix after firing.

---

## Supply

### [Supply] Cone-6 casting slip shrinkage variance — Medium

**Symptom:** Two batches of "Cone 6 stoneware casting slip" from the
same supplier shrink 11.5% and 13.0% respectively. Master scale factor
1/(1 - shrinkage) shifts by ~1.5% (from 1.130 to 1.149), enough to
push a tuned body 30–40 ¢ off target.

**Mechanism:** Shrinkage is a function of clay particle size, water
content, organic content, and firing schedule. Manufacturers specify
a *nominal* shrinkage; actual shrinkage is batch-dependent and the
spec is rarely tighter than ±1.5%.

**Test:** Pour three shrinkage coupons (4" × 1" × 0.25" bars) per
new slip batch; bisque-fire all three; measure shrinkage; record in
`validation.csv` shrinkage column.

**Mitigation:** **Re-derive** the master scale factor from the
*measured* batch shrinkage before printing each new master, not from
the workbook's 12% assumption. The OpenSCAD master takes shrinkage as
a parameter; this is already wired in, but the procedure must be
called out in the assembly manual.

**Severity:** Medium — process-controllable. Skipping the coupon
test is the failure mode, not the slip itself.

---

### [Supply] Bambu X1C build envelope vs UDU-L/XL master — High

**Symptom:** Bambu X1C build volume is ~256 × 256 × 256 mm (~10" cube).
UDU-L master half is 12" tall × 12" wide × 6" deep at 12% shrinkage
scaling — exceeds the print bed in two dimensions. UDU-XL is worse.

**Mechanism:** Master halves print as one-shot solids for surface
finish; splitting them adds layer-line discontinuities that telegraph
into the plaster mold and ultimately the cast surface.

**Test:** Open the UDU-L master.scad output in OpenSCAD, export STL
sliced as a half, load in BambuStudio — confirm "out of build volume"
warning before printing.

**Mitigation:** Three options:
1. **Multi-section masters** — split each L/XL master into 2–3
   stackable sections, glue and surface-fill at the joint, sand smooth
   before plaster pour.
2. **Outsource print** — Shapeways, Craftcloud, or local Maker Nexus
   bay with a larger printer (Prusa XL, Voron 350+ build, 600 mm
   format).
3. **Defer L/XL until the print farm grows** — UDU-S and UDU-M fit
   the X1C; ship those first. (Already explicitly called out in the
   README "Status" table.)

**Severity:** **High** for UDU-L/XL — design constraint that must be
resolved before Tier-3 CAD. Escalated to Tony.

---

## Fit / Finish

### [Fit/Finish] Glaze adhesion at port edge — Low

**Symptom:** Wax resist at the mouth and side-hole rim is meant to
keep the rim glaze-free for hand contact. A thin or uneven wax
application lets glaze creep onto the rim during dipping; the rim
glaze then chips off in service or feels gritty under the hand.

**Mechanism:** Wax resist relies on the contact angle between liquid
glaze and a hydrophobic film. Low-temperature wax (<140 °F drip
point) re-wets if the bisque body is warm from a kiln just opened.
Brush strokes leave thin spots.

**Test:** Wax-resist a bisque coupon along a pencil-marked line;
dip-glaze; bisque-fire; inspect line edge under raking light for
glaze creep.

**Mitigation:** Wax under cool conditions (≤80 °F). Two thin coats
beat one thick coat. Inspect each rim before glaze fire; touch up wax
gaps. Specify the wax type in `bom.csv` (currently "wax resist" — too
generic).

**Severity:** Low — easy to catch at QC, affects play comfort if missed.

---

### [Fit/Finish] Master split-line transfer to cast body — Medium

**Symptom:** The two-piece plaster mold has a parting seam where the
mold halves meet. Casting transfers a fine ridge along this seam onto
the greenware body. If the seam runs through the hand-contact zone,
the player feels a subtle bump on each strike.

**Mechanism:** The mold split is geometrically necessary for demold;
no slip-cast body avoids it. The skill is to *route* the split line
away from hand-contact surfaces.

**Test:** Trace the proposed split line on the master CAD; overlay
the hand-contact heat-map (mouth seal palm + side-hole slap fingers).
Any overlap is a design issue; relocate the split line.

**Mitigation:** Position split line on the front-back equator of the
body, not on the side-hole face. Trim split-line ridge with a damp
fettling tool at leather-hard; final smooth before bisque.

**Severity:** Medium — design + process. Already addressed in the
mold strategy of `design.md`; this risk register documents the *why*.

---

## Cross-cutting / lineage

### [Cultural] Public-facing copy must respect Igbo lineage — High (procedural)

**Symptom:** Listing the udu in a recruiter-facing portfolio without
the lineage attribution reads as appropriative or naïve. The udu is
not a generic ceramic bass pot.

**Mechanism:** Documentation is a public artifact even when the build
is private. Recruiters, students, and other makers will read the
README and the build-log site without context.

**Test:** Pre-publication review by a knowledgeable second reader
(family member, cultural-sensitivity reader, or peer maker familiar
with West African instrument lineage). Sign-off recorded in `notes/`
before the build-log site goes live.

**Mitigation:** The README, `design.md`, and the build-log site each
carry an explicit attribution paragraph. The license clause (CC-BY 4.0)
is for the *engineering documentation*, not for the instrument concept
itself. Already captured in the LICENSE file and design.md "Cultural
And Product Note" — this risk register documents the *requirement*,
not a defect.

**Severity:** High (procedural — block publication of build-log site
until pre-pub review is signed).

---

## Risk summary

| ID | Category | Severity | Status |
|---|---|---|---|
| ACO-01 | Acoustic — family-extremes target mismatch | High | Escalated |
| ACO-02 | Acoustic — coupled-mode unmodeled | Medium | Empirical loop |
| ACO-03 | Acoustic — glaze-fire pitch shift | Medium | Process |
| STR-01 | Structural — port-edge wall margin | Medium | Process |
| STR-02 | Structural — XL greenware crack | Medium / High XL | Escalated for XL |
| ERG-01 | Ergonomic — side-hole reach | Low | Documentation |
| ERG-02 | Ergonomic — mouth rim sharpness | Medium | Master-CAD |
| SUP-01 | Supply — slip shrinkage variance | Medium | Process |
| SUP-02 | Supply — Bambu envelope vs L/XL | High | Escalated |
| FIT-01 | Fit/Finish — glaze creep at port edge | Low | QC |
| FIT-02 | Fit/Finish — split-line transfer | Medium | Master-CAD |
| CUL-01 | Cultural — lineage attribution | High procedural | Pre-pub review |

**High-severity, escalated to human:** ACO-01 (family-extremes target
mismatch), STR-02 (XL crack risk), SUP-02 (Bambu envelope), CUL-01
(pre-pub review).

These four block declaring the v4.1 udu packet "production-tagged" until
Tony resolves them.

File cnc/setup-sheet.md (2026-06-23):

# CNC Setup Sheet — Udu — Slip-Cast Ceramic Vessel Drum Family

> **Status: placeholder** — populate from design.md dimensions and update after
> first successful machining run.

## Machine

- Machine: TBD (CNC router / laser / lathe)
- Controller: TBD
- Work envelope: TBD

## Stock

| Dimension | Value | Notes |
|---|---|---|
| Material  | TBD | |
| Thickness | TBD | |
| Width | TBD | |
| Length | TBD | |

## Datums

- **A** — drum center axis (spindle center for lathe; work-origin X0Y0 for router).
- **B** — front face / head side.

## Operations

| # | Operation | Tool | Speed | Feed | Depth | Notes |
|---|---|---|---|---|---|---|
| 1 | Rough profile | TBD | TBD | TBD | TBD | |
| 2 | Bearing-edge radius | TBD | TBD | TBD | TBD | Match design.md |
| 3 | Finish pass | TBD | TBD | TBD | TBD | |

## Release Checks

- [ ] Datum offsets confirmed against physical stock.
- [ ] Bearing-edge radius within ±0.5 mm of design.
- [ ] Shell roundness within 1 mm TIR.
- [ ] No tool marks on head seat.

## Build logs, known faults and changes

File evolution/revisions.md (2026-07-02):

# Revision Register — udu

| Rev | Date | Parent | Delta | Downstream artifacts invalidated |
| --- | --- | --- | --- | --- |
| A | 2026-07-01 | — | Stage 0 intake of current masters (cad/udu_master.scad + family-spec.csv). | none (no alpha/beta/production artifacts exist yet) |

Stage 0 only. Gate A has not been run; no Alpha compiles, vendor quotes, or production lock exist for this product.

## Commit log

2026-05-02 Scaffold: LICENSE, .gitignore, design table, README
    [udu-design-table.xlsx]
2026-05-02 Migrate build packet from instrument-maker/docs/build-packets/udu-drum-family
    [bom.csv, sourcing.csv, validation.csv]
2026-05-02 Generate full build packet via instrument-maker [v1 codex]
    Tier 1: cut-list, supplier-rfq, capstone-deck (md+pptx, 9 slides),
    print-packet (md+html+pdf, 49 pp via weasyprint fallback - v1 codex
    skill has no native PDF generator), capstone-manifest, README rewrite.
    Tier 2: cad/udu_master.scad (family-aware, S/M/L/XL with inline
    Helmholtz calcs), drawings/ (3 SVGs: body section, mold split,
    family scale), images/ (2 concept renders).
    Tier 3 (.step/.stl/.dxf) deferred until UDU-P2 medium validation.
    Skill: skills/codex/instrument-maker/SKILL.md
    Tracking issue: tonykoop/instrument-maker#82
    [cut-list.csv, udu_master.scad]
2026-05-18 Add V5 explorer readiness packet (#2)
    [family-spec.csv, visual-output-register.csv]
2026-05-31 Add image-gen concept prompt; wire explorer images
2026-06-23 feat(v5): explorer V5 upgrade + build-packet gaps — udu (#5)
    * feat(v5): upgrade explorer to V5 format + fill build-packet gaps
    - Replace explorer.html with V5 parchment card format: readiness chip,
    authority-split chip, family chip, per-artifact authority badges
    (fabrication / derived_preview / reference_only / source_only)
    - Add data/deliverables-export.json machine-readable manifest
    - Add any missing build-packet stubs (drawing-brief.md, assembly-manual.md,
    supplier-rfq.md, visual-bom-brief.md, photo-shotlist.md, sourcing.csv,
    cut-list.csv, cnc/setup-sheet.md) as TBD-ready placeholders
    Refs instrument-maker v4.5 · tonykoop/udu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
    [visual-output-register.csv]
2026-07-02 V5 packet refresh: honest L1 status line + provenance rows (minimal touch)
    Per V5 percussion addendum status-normalization rule: "explorer/readiness
    scaffold — not a candidate" -> L1 concept packet, do NOT call it L2 when the
    README explicitly denies candidacy (docs/v5-readiness.md: "not a full V5
    build-packet candidate"). Caveat prose preserved verbatim.
    - README.md: rewrite the "## Status" line to the approved
    "**Status:** L1 concept packet" form while keeping all existing readiness
    caveats (fired prototype measurements / DXF / CAD renders / exploded
    diagram / assembly plate / MCP provenance still missing).
    - cad/mcp-session-log.md: add 3 provenance rows (existing repo-native sche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
2026-07-02 Evolution-pipeline Stage 0 intake: master manifest, design-intent, revision register
    Complements the minimal-touch V5 refresh (a8e3c52); Gate A not run.
